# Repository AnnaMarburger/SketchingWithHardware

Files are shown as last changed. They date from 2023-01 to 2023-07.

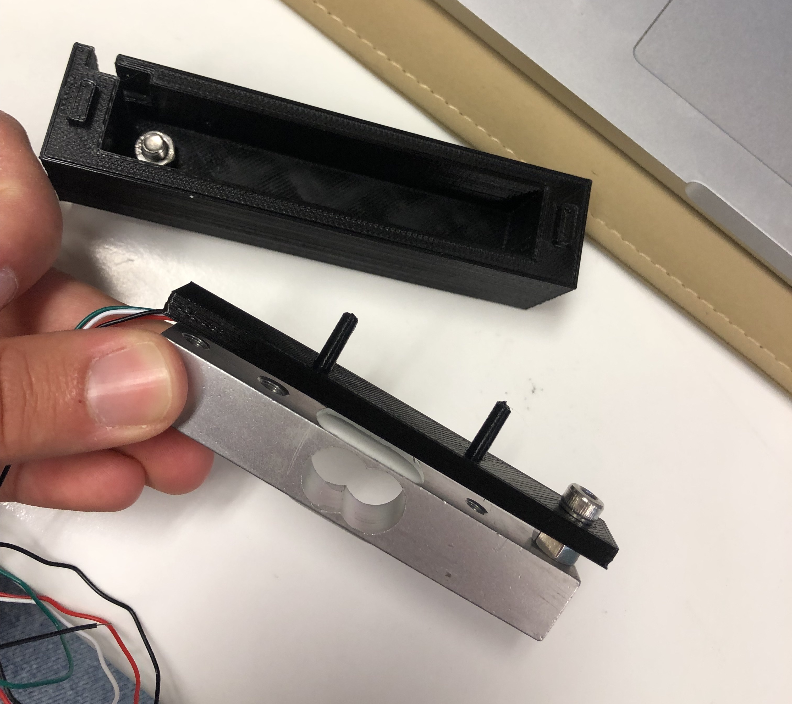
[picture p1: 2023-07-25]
content/posts/media/projekt/assemble_gewichtssensor.jpeg

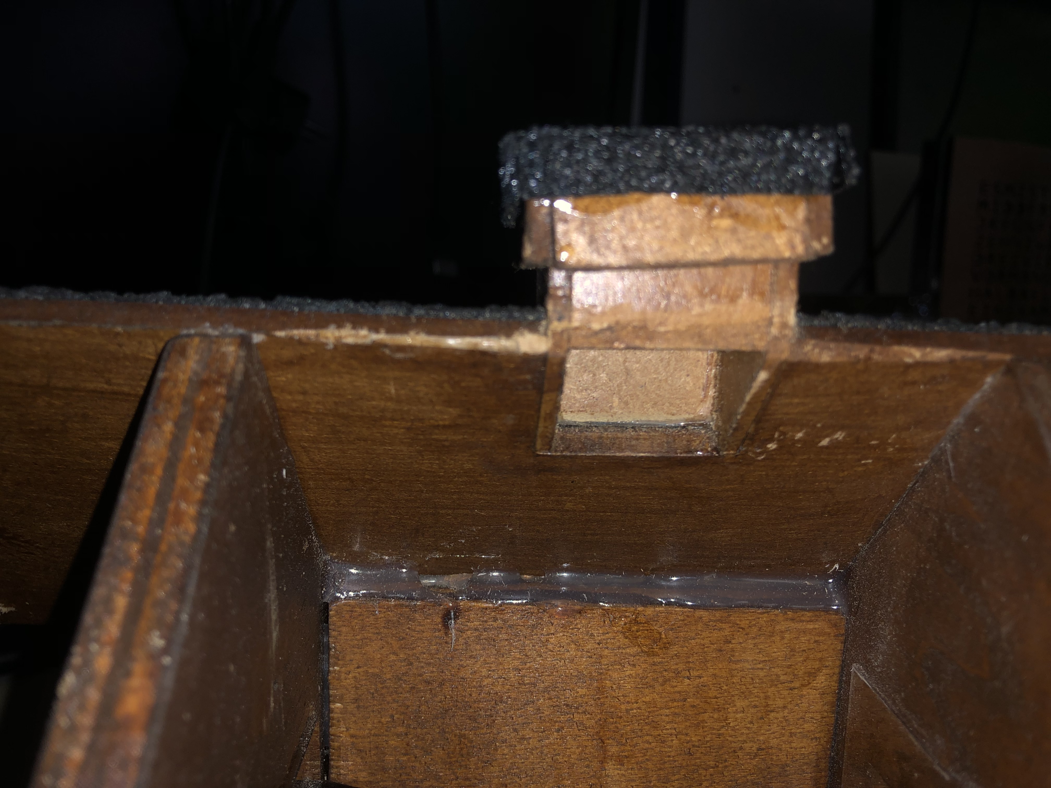
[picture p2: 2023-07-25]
content/posts/media/projekt/dach.jpeg

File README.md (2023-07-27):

### Sketching With Hardware I + II
Im WS 2022/23 und SS 2023 an der Universität. Der Blog findet sich auf: [annamarburger.github.io](https://annamarburger.github.io/swh/).

Im Ordner *birdbooth_files* finden sich alle Dateien, die für den Nachbau des Projekts **BIRD BOOTH** notwendig sind [(Anleitung)](https://annamarburger.github.io/swh/posts/post9/).

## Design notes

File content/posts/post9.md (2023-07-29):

---
title: "09 - Nachbauanleitung: Bird Booth"
date: 2023-07-11T12:28:26+02:00
show_reading_time: true
featured_image: "/media/haus_drawing.png"
draft: false
---

## Einleitung

Das Projekt Bird Booth entstand aus der Idee, auch viel beschäftigten Vogelliebhabern die Möglichkeit zu bieten, ihre Besucher zu sehen, und nicht nur das langsam verschwindende Futter über die Zeit zu beobachten. Das smarte Futterhäuschen liefert Bilder und Gewicht von alle Vögeln, die sich an dem Futter bedienen. Das Gewicht liefert einen zusätzlichen Wiedererkennungswert und lässt Beobachter zum Beispiel auch Rückschlüsse auf Gesundheit und Zustand der tierischen Besucher ziehen.
Bird Booth soll ein langlebiges und umweltfreundliches Vogelhäuschen sein.

{{< rawhtml >}} 
    <br>
{{< /rawhtml >}}
### Materialien und Zubehör

##### Technik
-  ESP32 CAM 2,4 GHz WiFi mit OV2640 Kamera Modul
-  Elektronischer Gewicht Sensor (3kg)
-  HX711 LoadCell Amplifier
-  Vibrationssensor SW420
-  Batterie-Case mit 3x AAA-Batterien(1,5V)

##### Zusätzliches Material
- 2 Lochraster-Platinen
- Kleines Scharnier einschließlich Schrauben
- Holzlasur auf Wasserbasis
- Holz nach Wahl (5 Platten mit 1cm Dicke für Wände und Boden, 4 Platten mit 3mm für das Dach, Zwischenboden und Futterplatte)
- Dachpappe
- 2 kleine Plexiglasplatten
- 2 kleine Magnete
- 2x Schrauben (Maße: Durchmesser  5mm, Kopfdurchmesser max. 9mm, Länge ca 25mm), einschließlich 2 passenden Muttern
- Eine Schraube (Maße: Durchmesser 5mm, Kopfdurchmesser max. 9mm, Länge 15-25mm), einschließlich passender Mutter (Für Sensor-Case unten)
- Eine Schrauben (Maße: Durchmesser 4mm, Kopfhöhe max. 4.5mm, Länge 15-25mm), einschließlich passender Muttern (Für Sensor-Case Innen)
- 8 kleine Nägel
- Holzstab Durchmesser 10mm, Länge 105mm

##### Zubehör
- FTDI232 Adapter (USB auf Serielles TTL) und USB Kabel
- 3D-Drucker mit PLA Filament
- Bandsäge und Stichsäge
- Akku-/Bohrschrauber
- Holzleim, 2-Komponenten-Kleber, Heißkleber
- Kabel, Lötzubehör, Schrumpfschläuche

##### Zum Testen
- Steckplatine
- Jumperkabel

##### Optional
- weiße Acrylfarbe
- kleine, platte Holzstäbchen für die Fensterrahmen
- Makramee-Fäden

{{< rawhtml >}} 
    <br>
{{< /rawhtml >}}
### Dateien-Bibliothek
#### Code
- [Server Code ](https://github.com/AnnaMarburger/smartesfutterhaus)
- [ESP Code ](https://github.com/AnnaMarburger/swh/blob/main/birdbooth_files/esp_code.ino)

#### 3D-Druck-Modelle (.stl)
- [Sensor-Case Deckel ](https://github.com/AnnaMarburger/swh/blob/main/birdbooth_files/sensorcase_deckel.stl)
- [Sensor-Case Zwischenblatt](https://github.com/AnnaMarburger/swh/blob/main/birdbooth_files/sensorcase_zwischenblatt.stl)
- [Sensor-Case Unterteil](https://github.com/AnnaMarburger/swh/blob/main/birdbooth_files/sensorcase_unten.stl)
- [Futterschale Unterteil](https://github.com/AnnaMarburger/swh/blob/main/birdbooth_files/futterschale_unten.stl)
- [Kamera-Case](https://github.com/AnnaMarburger/swh/blob/main/birdbooth_files/cam-case.stl)

#### Lötplan
- [schaltplan.png ](https://github.com/AnnaMarburger/swh/blob/main/birdbooth_files/schaltplan.png)

{{< rawhtml >}} 
    <br>
{{< /rawhtml >}}
## Schritt-für-Schritt Anleitung

### 1. Website programmieren, Server aufsetzen und hosten

{{< figure src="../media/projekt/server_desktop.png" >}}

#### 1.1 Projekt aufsetzen, Umgebungen installieren

Um später die Bilder der Futterhaus-Kamera zusammen mit den Gewichtsdaten von überall einsehen zu können, setzen wir einen Server auf. Dieser soll zum einen POST-Requests mit den Daten, die wir später von dem Kamera Modul senden, annehmen und in einer Datenbank speichern können. Zum anderen soll er Webclients, die unsere Website aufrufen, eine HTML mit den aufgearbeiteten Daten (Bildern) zurückgeben.

Um den Server zu realisieren verwende ich die Laufzeitumgebung [Node Js](https://nodejs.org/de). Ist diese noch nicht installiert, sollte dies zuerst geschehen. 

Nun legen wir ein Verzeichnis an, in welchem wir unsere Anwendung aufbauen. Mit `npm init` wird eine neue package.json Datei erstellt. In dieser können wir unter anderem den Namen unserer Anwendung festlegen, sowie unter “main” den Namen unsere Hauptdatei, die für das Starten des Servers verantwortlich ist. Bevor wir genau diese Datei anlegen, in meinem Fall “app.js”, fügen wir der package.json Datei ein weiteres Attribut hinzu: `“type”:module`. 

Um das Coden einfacher zu  gestalten, verwende ich das Framework  [Express Js](https://expressjs.com)  . Dieses lässt sich mit dem Package Manager npm durch `npm install express` installieren. Dabei ist wichtig, dass wir uns im Verzeichnis unserer Anwendung befinden. Mit `node app.js` kann der Server lokal getestet werden. Hierzu ist zudem das Programm [Postman](https://www.postman.com) hilfreich, das über eine einfache Benutzeroberfläche Server Requests verschicken lässt 

  {{< figure src="../media/projekt/postman_request.png" caption="Screenshot POST-request in Postman">}}

(Achtung: Für Anfragen an lokale Server wird hierbei die Desktop App benötigt).

#### 1.2 Datenspeicherung mit Firebase

Für die Datenspeicherung verwende ich Firebase. Um das Projekt dort anzulegen, wird ein Konto benötigt. Anschließend kann über “Projekt hinzufügen”, ein neues Projekt erstellt werden. Ist dies getan, öffnet sich die Konsole für das Projekt. Dort sollte die App dem Projekt hinzugefügt werden. Da wir eine Webanwendung bauen, wählen wir dort “Web” aus und geben den Namen unseres Servers ein. Über Firebase kann der Server später auch gehostet werden, dann sollte der Haken bei dieser Option gesetzt werden. Ich habe dafür jedoch einen anderen (kostenlosen) Anbieter gewählt: [Render](https://render.com/). Anschließend muss firebase in unserem Projekt installiert werden: `npm install firebase`. Firebase zeigt nun einen Codeblock an:

```jsx
// Import the functions you need from the SDKs you need
import { initializeApp } from "firebase/app";

// Your web app's Firebase configuration
const firebaseConfig = {
  apiKey: "...",
  ...
};

// Initialize Firebase
const app = initializeApp(firebaseConfig);
```

Wichtig hier ist die Firebase Configuration für unsere Anwendung, da diese für jedes angelegte Firebase Projekt individuell ist. Dieser Teil muss also kopiert und in unserer Hauptdatei *app.js* entsprechend ersetzt werden. Nun müssen wir in der Firebase Konsole nur noch unseren Speicher einrichten. Unter “Entwickeln” im Seitenmenü wählen wir “Storage” aus und drücken auf der Seite auf “Jetzt Starten”.  Die Sicherheitsregeln setzen wir (zum Entwickeln) auf öffentlich. In diesem Speicherbucket können wir nun einen Ordner “images” erstellen. Hier lädt unser Server alle einkommenden Bilder hoch. 

  {{< figure src="../media/projekt/screen_firebase.png" caption="Screenshot des Firebase-Storage">}}

Außerdem muss die Datei *data.json* in diesem Storage von Hand erstmals hochgeladen werden, da der Server versucht, diese herunterzuladen, sobald er eine “GET” Request von einem Clienten erhält. Beim allerersten Serverstart würde dieser dementsprechend einen Fehler werfen, wenn er dort keine *data.json* Datei findet.

#### 1.3 Hosting

Für das Hosten des Servers auf Render wird lediglich ein GitHub Repository mit dem Servercode benötigt. Der Anbieter deployed mit jedem Commit den Server erneut. Außerdem gibt es eine Konsole, in der Ausgaben des Servers eingesehen werden können (Hilfreich zum Debuggen). Render selbst führt gut verständlich durch den Hosting Prozess.

#### 1.4 **Aufbau des Servers:**

Der gesamte Code für den Server ist auf folgendem Repo zu finden: 

https://github.com/AnnaMarburger/smartesfutterhaus

1. Die *app.js* Datei, auch die Hauptdatei, die für das eigentliche Erstellen des Servers verantwortlich ist. In dieser Datei werden “POST”, “GET” und “DELETE” Anfragen gehändelt. Einkommende POST Anfragen werden auf Richtigkeit geprüft und anschließend bearbeitet. Bilder werden direkt mit einem eindeutigen Namen (durch Datum+Uhrzeit) im Firebase Storage gesichert. 

2. Die *index.html* Datei ist die Datei, welche an Clienten bei GET Requests geschickt wird. In ihr werden die Buttons zum Filtern und Sortieren definiert. Außerdem sind in ihr die Dateien *gallery.js* und *style.css* verlinkt.

Im *Public Ordner*, welchen wir als solchen in *app.js* deklarieren (dies ist wichtig, um Clienten den Zugriff auf benötigte Dateien wie z.B. stylesheets möglich zu machen, die wir nicht per se mitschicken):

3. *gallery.js* ist die JavaScript Datei, die sich um das dynamische Anzeigen der Daten auf der Website kümmert. Sie liest aus der “data.json” jeweils Bildname, zugehöriges Gewicht und Datum aus und zeigt diese Daten für jeden Eintrag als Galerie-Item auf der Website an. Des Weiteren händelt sie die Filter- und Sortierungs-Optionen, die durch die Buttons auf der Seite getriggert werden. 

4. In der Datei *style.css* wird das Aussehen der Website entsprechend festgelegt.

5. Die bereits erwähnte *data.json* Datei verwaltet die Metadaten zu jedem Bild, das den Server erreicht. Dazu gehören Name der Bilddatei, sodass sie in den Files gefunden werden kann, das gemessene Gewicht des zugehörigen Vogels sowie einen Datumsstempel, der beim Empfangen des Bildes hinzugefügt wurde.

Der *Uploads Ordner* enthält die Bilddateien zum Anzeigen nach Herunterladen aus dem Firebase Speicher.

{{< rawhtml >}} 
    <br>
{{< /rawhtml >}}
### 2. Kameramodul

#### 2.1 Schaltplan

Unsere Kamera-Komponente besteht aus zwei Teilen: Zum einen die ESP32-Cam, die mit einem ESP32 Microchip arbeitet, zum anderen das OV2640 Kameramodul, sprich die Kamera selbst. Werden beide Teile getrennt geliefert, so muss der längliche Klipser auf der ESP32-Cam vorsichtig aufgemacht und das Kameramodul so reingeschoben werden, dass die Kamera nach vorne zeigt und sicher hält.

Da die ESP32-Cam keinen USB-Anschluss mitbringt, benötigen wir, um sie zu programmieren, einen USB-to-TTL Adapter, wie zum Beispiel den FTDI. Diesen können wir mithilfe eines Breadbords anschließen:

  {{< figure src="../media/projekt/steckplatine.jpeg" width="60%"  caption="ESP+FTDI auf Steckplatine">}}

Dabei sollten wir darauf achten, dass auf dem Adapter die Bridge zu 5V gesetzt ist. Zwar läuft der Esp laut Dokumentation auch mit 3.3V, jedoch wurden hierbei zahlreiche Probleme in Online Foren reported. Zusätzlich müssen wir die ESP32-Cam, um Code hochladen zu können, in den “Flashing Mode” setzen. Dies machen wir, indem wir die Pins GPIO0 und GND verbinden. Der Schaltplan sieht demnach folgendermaßen aus:

  {{< figure src="../media/projekt/schaltplan_esp.jpeg" caption="Schaltplan ESP+FTDI">}}

#### 2.2 Programmieren

 Um den ESP-32 Microchip programmieren zu können, müssen wir das Board in der Arduino IDE installieren. Dazu fügen wir in den Einstellungen folgenden Link dem Feld “Additional boards manager URLs” hinzu und speichern:

https://dl.espressif.com/dl/package_esp32_index.json 

Im Boards Manager können wir nun nach “esp32” suchen und installieren. Anschließend sollten wir unter Tools>Board>esp32 die “AI Thinker Esp32 Cam” auswählen können. Unter Port wählen wir den entsprechenden USB Port aus, an welchem wir den Adapter eingesteckt haben.

  {{< figure src="../media/projekt/select_AIThinkerCam.png" caption="Screenshot Board-Auswahl">}}

Unter File > Examples gibt es verschiedene Beispielprogramme, um den ESP zu testen, so auch zum Beispiel auch ein Programm, dass auf einem lokalen Server einen Livestream der Kamera startet und die verschiedensten Einstellungen treffen lässt. Der Code findet sich unter File > Examples > ESP32 > Camera > CameraWebServer. 

Während dem Upload des Codes, wenn auf der Konsole “Connecting…” erscheint, muss das Board einmal resettet werden. Auf der Rückseite gibt es dazu einen kleinen Reset-Knopf. Da man daran aber schlecht herankommt, wenn man ein Breadboard verwendet, kann man alternativ das Kabel zu 5V am Board kurz aus- und wieder einstecken.

Nun sollten wir dazu bereit sein, unseren eigentlichen Code für die ESP32-Cam zu schreiben. Wir erstellen eine neue Arduino Datei. Zunächst brauchen wir folgende Libraries:

```cpp
#include <Arduino.h>
#include <WiFi.h>
#include <WiFiClientSecure.h>
#include "soc/soc.h"
#include "soc/rtc_cntl_reg.h"
#include "esp_camera.h"
```

Anschließend legen wir folgende Variablen für die WiFi Connection fest:
```cpp
//WIFI
const char* ssid = "INSERT_YOUR_SSID";
const char* password = "INSERT_PASSWORD_FOR_SSID";
String serverName = "INSERT_SERVER_URL"; //for me: smartesfutterhaus.onrender.com
String serverPath = "/"; 
const int serverPort = 443; //server port for HTTPS
WiFiClientSecure client;
```

Hierbei müssen SSID und Passwort natürlich mit den eigenen Werten gefüllt werden, sprich mit Name und Passwort der WLAN-Verbindung. Auch die Server-URL muss individuell eingetragen werden. 

Um die AI-Thinker Camera vom ESP32 zu verwenden, müssen wir folgende Pins definieren:
```cpp
// CAMERA_MODEL_AI_THINKER
#define PWDN_GPIO_NUM     32
#define RESET_GPIO_NUM    -1
#define XCLK_GPIO_NUM      0
#define SIOD_GPIO_NUM     26
#define SIOC_GPIO_NUM     27
#define Y9_GPIO_NUM       35
#define Y8_GPIO_NUM       34
#define Y7_GPIO_NUM       39
#define Y6_GPIO_NUM       36
#define Y5_GPIO_NUM       21
#define Y4_GPIO_NUM       19
#define Y3_GPIO_NUM       18
#define Y2_GPIO_NUM        5
#define VSYNC_GPIO_NUM    25
#define HREF_GPIO_NUM     23
#define PCLK_GPIO_NUM     22
```

Nun konfigurieren wir in der setup Methode zum einen die WiFi-Verbindung (wir verwenden den STA Modus), zum anderen die Kamera (diese ist durch das Modell erneut vorgegeben).
Zuletzt versuchen wir, die Cam zu initialisieren. Tritt hierbei ein Fehler auf, soll eine Fehlermeldung ausgegeben werden und nach einem kurzen Delay ein Neustart des ESP hervorgerufen werden. 
```cpp
//SETUP
void setup() {
  WRITE_PERI_REG(RTC_CNTL_BROWN_OUT_REG, 0); //BROWN OUT DETECTOR
  Serial.begin(115200); //BAUD RATE

  //WIFI setup
  WiFi.enableSTA(true);
  WiFi.mode(WIFI_STA);

  //CAM config
  camera_config_t config;
  config.ledc_channel = LEDC_CHANNEL_0;
  config.ledc_timer = LEDC_TIMER_0;
  config.pin_d0 = Y2_GPIO_NUM;
  config.pin_d1 = Y3_GPIO_NUM;
  config.pin_d2 = Y4_GPIO_NUM;
  config.pin_d3 = Y5_GPIO_NUM;
  config.pin_d4 = Y6_GPIO_NUM;
  config.pin_d5 = Y7_GPIO_NUM;
  config.pin_d6 = Y8_GPIO_NUM;
  config.pin_d7 = Y9_GPIO_NUM;
  config.pin_xclk = XCLK_GPIO_NUM;
  config.pin_pclk = PCLK_GPIO_NUM;
  config.pin_vsync = VSYNC_GPIO_NUM;
  config.pin_href = HREF_GPIO_NUM;
  config.pin_sscb_sda = SIOD_GPIO_NUM;
  config.pin_sscb_scl = SIOC_GPIO_NUM;
  config.pin_pwdn = PWDN_GPIO_NUM;
  config.pin_reset = RESET_GPIO_NUM;
  config.xclk_freq_hz = 20000000;
  config.pixel_format = PIXFORMAT_JPEG;

  // init with high specs to pre-allocate larger buffers
  if(psramFound()){
    config.frame_size = FRAMESIZE_SVGA;
    config.jpeg_quality = 10;  //0-63 lower number means higher quality
    config.fb_count = 2;
  } else {
    config.frame_size = FRAMESIZE_CIF;
    config.jpeg_quality = 12;  //0-63 lower number means higher quality
    config.fb_count = 1;
  }
  
  // CAM init
  esp_err_t err = esp_camera_init(&config);
  if (err != ESP_OK) {
    Serial.printf("Camera init failed with error 0x%x", err);
    delay(1000);
    ESP.restart();
  }
}
```

In einer zusätzlichen Methode schreiben wir folgenden Code, um uns mit dem WiFi zu verbinden:
```cpp
void connectWiFi(){
  WiFi.enableSTA(true);
  WiFi.mode(WIFI_STA);
  delay(10);
  WiFi.begin(ssid, password);
  int counter = 0;

  while( WiFi.status() != WL_CONNECTED) {
    delay(1000);
    Serial.println("Connecting to WiFi.. > status : " + String(WiFi.status()));
    counter++;
    if(counter >= 25){
      WiFi.begin(ssid, password);
      counter = 0;
    }
  }
}
```
Diesen werden wir später jedes Mal aufrufen, wenn wir den ESP aus seinem sleep modus aufwecken. 

Außerdem schreiben wir eine Methode, die für das tatsächliche Versenden des Fotos verantwortlich ist. Dabei holen wir uns zuerst einen Pointer zum Kamera Frame-Buffer (und starten den ESP neu, falls dies fehlschlagen sollte). Anschließend bauen wir eine Verbindung zu unserem Server auf. Schließlich schreiben wir die Request, senden sie ab und warten auf die Antwort des Servers (dies ist hauptsächlich für Debugging-Zwecke nötig und kann letztendlich weggelassen werden, da wir die Antwort nicht weiter verarbeiten. Alternativ kann bei einer Fehlerausgabe ein erneutes Versenden ausgelöst werden; Darauf habe ich, um die Code Komplexität zu verringern, verzichtet).

```cpp
void sendPhoto() {
  String getAll;
  String getBody;
	
  //get Camera Capture
  camera_fb_t * fb = NULL;
  fb = esp_camera_fb_get();
  if(!fb) {
    Serial.println("Camera capture failed");
    delay(1000);
    ESP.restart();
  }
  
  Serial.println("Connecting to server: " + serverName);
  
  client.setInsecure(); //skip certificate validation
  if (client.connect(serverName.c_str(), serverPort)) {

    Serial.println("Connection successful!");  

    //send request           
    String head1 = "--XXX\r\nContent-Disposition: form-data; name=\"password\"\r\n\r\nSWH2023\r\n--XXX\r\nContent-Disposition: form-data; name=\"weight\"\r\n\r\n";
    String head2 = head1 + weight;
    String head = head2 + "\r\n--XXX\r\nContent-Disposition: form-data; name=\"img\"; filename=\"esp32-cam.jpg\"\r\nContent-Type: image/jpeg\r\n\r\n";
    String tail = "\r\n--XXX--\r\n";
    
    uint32_t imageLen = fb->len;
    uint32_t extraLen = head.length() + tail.length();
    uint32_t totalLen = imageLen + extraLen;
  
    client.println("POST " + serverPath + " HTTP/1.1");
    client.println("Host: " + serverName);
    client.println("Content-Length: " + String(totalLen));
    client.println("Content-Type: multipart/form-data; boundary=XXX\r\n\r\n");
    client.print(head);
  
    //send img
    uint8_t *fbBuf = fb->buf;
    size_t fbLen = fb->len;
    for (size_t n=0; n<fbLen; n=n+1024) {
      if (n+1024 < fbLen) {
        client.write(fbBuf, 1024);
        fbBuf += 1024;
      }
      else if (fbLen%1024>0) {
        size_t remainder = fbLen%1024;
        client.write(fbBuf, remainder);
      }
    }   
    client.print(tail);
    
    esp_camera_fb_return(fb);
    
    int timoutTimer = 180000;
    long startTimer = millis();
    boolean state = false;
    
    //read answer
    while ((startTimer + timoutTimer) > millis()) {
      Serial.print(".");
      delay(500);      
      while (client.available()) {
        char c = client.read();
        if (c == '\n') {
          if (getAll.length()==0) { state=true; }
          getAll = "";
        }
        else if (c != '\r') { getAll += String(c); }
        if (state==true) { getBody += String(c); }
        startTimer = millis();
      }
      if (getBody.length()>0) { break; }
    }
    Serial.println();
    client.stop();
    Serial.println(getBody);
  }
  else {
    Serial.println("Connection to " + serverName +  " failed.");
  }
}
```

Achtung: Um den Code zu testen, muss "weight" durch eine beliebige Zahl ersetzt werden. Diese Variable haben wir bisher noch nicht definiert. Dies werden wir in Abschnitt 4 tun, wenn es um den Gewichtssensor geht.
Um beim Testen das Output des Programms sehen zu können, öffnen wir unter Tools > Serial Monitor den Serial Monitor und beachten dabei, dass er auf die richtige BAUD Rate (hier 115200) eingestellt ist.

**Troubleshooting**: Beim Hochladen von Code auf den ESP kommt es gerne mal zu Problemen, oftmals liegt es an manelhafter Stromversorgung. Hier hilft Google weiter. Eine für mich hilfreiche Seite war: [espressif docs](https://docs.espressif.com/projects/arduino-esp32/en/latest/troubleshooting.html).

{{< rawhtml >}} 
    <br>
{{< /rawhtml >}}
### 3. Weckfunktion mit Vibrationssensor

Damit der ESP in den light sleep geschickt werden kann, während keine Vögel zu Besuch sind, wird ein Vibrationssensor benötigt, um den ESP auch wieder aufwecken zu können. Dazu ergänzen wir unseren Code folgendermaßen:

- Wir ergänzen in der setup Methode am Ende: 
    ```cpp
    //lightsleep init
    pinMode(15, INPUT);
    gpio_wakeup_enable(GPIO_NUM_15, GPIO_INTR_HIGH_LEVEL);
    esp_sleep_enable_gpio_wakeup();
    WiFi.disconnect(true);
    Serial.println("Gleich schlafen"); //debug output
    Serial.flush(); 
    delay(100);
    esp_light_sleep_start();
    delay(10);
    ```
    Hierbei ist Pin 15 der Pin, an den wir den Vibrationssensor anschließen. Wir legen diesen als WakeUp-Pin fest und trennen anschließend die WiFi-Verbindung. Dies ist nötig, um sie nach Erwachen aus dem sleep modus fehlerfrei wiederherstellen zu können. Anschließend starten wir direkt in den light sleep. Wenn der ESP durch ein Signal des Vibrationssensor geweckt wird, läuft der Code einfach weiter.

- Wir schreiben eine Methode, die mit jedem Erwachen aus dem sleep modus ausgeführt wird, unsere sogenannte WakeUp-Routine:
    ```cpp
    void wakeUpRoutine(){
        //reconnect to wifi and send image to server
        connectWiFi();
        sendPhoto();

        //back to sleep
        WiFi.disconnect(true);
        Serial.flush();
        delay(100);
        esp_light_sleep_start();
        delay(10);
        }
    ```
    Nach Senden des Fotos müssen wir, wie oben bereits erklärt, die WiFi Verbindung wieder trennen, bevor wir den ESP wieder in den sleep modus schicken.

- Nun können wir die loop-Methode schreiben, die sich so lange wiederholt, wie der ESP mit Strom versorgt wird:
    ```cpp
    void loop() {
        Serial.println("......... Woke Up ..................."); //debugging print
        wakeUpRoutine();
        delay(100);
    }
    ```
    In dieser brauchen wir nun lediglich unsere WakeUp-Routine aufzurufen. Ein loop-Durchgang entspricht also einem “Aufwachen”, da der ESP am Ende der WakeUp-Routine in den sleep modus versetzt wird.

{{< rawhtml >}} 
    <br>
{{< /rawhtml >}}
### 4. All about “Gewichtssensor”
Um mit den Daten des Gewichtssensors etwas anfangen zu können, brauchen wir ein Amplifier Modul (HX711). Der Schaltplan für diese beiden Komponenten sieht folgendermaßen aus:

{{< figure src="../media/projekt/schaltplan_loadcell.png" caption="Schaltplan Gewichtssensor">}}

Hierbei entsprechen die Farben der Kabel des Sensors auf dem Bild den Farben in echt und sollten dementsprechend verlötet werden. Um sicherzugehen ist es aber ratsam, in die Dokumentation der eigenen Teile zu schauen, falls Abweichungen auftreten. 

Das Schaubild zeigt außerdem, wie wir den Gewichtssensor montieren. Dazu brauchen wir folgende Bauteile:

{{< figure src="../media/projekt/bauteile_gewichtssensor.jpeg" width="60%"  caption="Gewichtssensor Bauteile">}}

- 3D-Modelle: Sensor-Case Deckel, Unterteil und Zwischenblatt
- Gewichtssensor mit Amplifier Modul
- 2 Schrauben einschließlich passender Muttern
- Holzstange

Die beiden Muttern dienen dabei als Spacer zwischen dem Gewichtssensor und dem unteren Teil des Cases, bzw. dem Waagblatt, das die Sitzstange hält und zwischen oberen Teil des Cases und Gewichtssensor liegt. Dies ist wichtig, damit der Sensor genug Platz hat, um bei Belastung nach unten gebeugt zu werden.

{{< figure src="../media/projekt/assemble_gewichtssensor.jpeg" width="60%"  caption="Gewichtssensor zusammenbauen">}}

Ist das Gehäuse zusammengesetzt, werden in die Holzstange (nachdem sie ebenfalls lasiert wurde) zwei Löcher mit 3mm Durchmesser gebort, so dass sie auf die beiden herausschauenden Stäbe gesteckt werden kann. Damit sie sicher hebt, habe ich sie mit 2-Komponenten-Kleber festgeklebt, dies sollte jedoch erst geschehen, wenn der Gewichtssensor zuverlässig funktioniert und das Case nicht mehr geöffnet werden muss. Das Case an sich habe ich nicht verklebt, da es durch den Steck-Mechanismus bereits ausreichend stabile Haftung vorwies.

{{< figure src="../media/projekt/gewichtssensor.jpeg" width="60%"  caption="Gewichtssensor fertig">}}

Um mit jedem Bild auch das aktuell gemessene Gewicht an den Server zu übermitteln, ergänzen wir den bisherigen Code für unseren ESP folgendermaßen:
- Das HX711 Modul benötigt eine Library, die wir inkludieren müssen:
    ```cpp
    #include "HX711.h"
    ```
    
- Des Weiteren definieren wir folgende Variablen, noch vor der setup-Methode:
    ```cpp
    //LOADCELL
    const int LOADCELL_DOUT_PIN = 13;
    const int LOADCELL_SCK_PIN = 12;
    const int calibrationfaktor = 380; //insert your own!
    long weight;
    HX711 scale;
    ```
    Die zwei Pins für DOUT und SCK entsprechen den Pins, die wir am ESP für den Sensor auswählen, ich habe hier Pin 12 und 13 gewählt.
    WICHTIG: Der Calibration-Factor ist für jeden Sensor ein anderer. Um diesen herauszufinden, müssen einige Objekte mit bekanntem Gewicht mit dem Sensor gewogen werden. Der Faktor berechnet sich dann folgendermaßen: 
    
    Calibration-Factor = Gemessenes Gewicht / Bekanntes Gewicht. 
    
    Es empfiehlt sich, dies mit einer gewissen Anzahl an Objekten zu machen und anschließen den Mittelwert der erhaltenen Faktoren zu nehmen, um am Ende möglichst genaue Daten zu erhalten.

- In der setup-Methode müssen wir nun unsere Waage initialisieren
    ```cpp
    //LOADCELL init
    scale.begin(LOADCELL_DOUT_PIN, LOADCELL_SCK_PIN);
    scale.set_scale(calibrationfaktor);
    scale.tare(5);
    ```
    Mit `scale.tare()` setzen wir die Waage auf Null. Wenn diese Methode aufgerufen wird, sollte sich also kein Gewicht auf dem Sensor befinden.

- Nun passen wir noch die WakeUp-Routine des ESP’s an, indem wir vor dem Senden des Fotos zunächst das Gewicht messen, und anschließend das Senden an den Server nur durchführen, wenn das Gewicht einen bestimmten Schwelle überschreitet. Dies verhindert, dass Fotos gesendet werden, wenn der Vibrationssensor fehlerhaft ausgelöst wurde (zum Beispiel durch ein fallendes Blatt oÄ.). Ich habe als Schwellwert 3 Gramm gewählt.
    ```cpp
    void wakeUpRoutine(){
        //get weight
        if (scale.is_ready()) { 
            weight = scale.get_units(20); //get the average of 20 readings
            Serial.print("Gewicht: "); //debug output
            Serial.println(weight);
        } else {
            Serial.println("HX711 not found.");
            weight = 0;
        }

        //check if an object is actually there or if scale empty
        if(weight > 3){
            //reconnect to wifi and send image to server
            connectWiFi();
            sendPhoto();
        }

        //back to sleep
        WiFi.disconnect(true);
        Serial.flush();
        delay(100);
        esp_light_sleep_start();
        delay(10);
    }
    ```

{{< rawhtml >}} 
    <br>
{{< /rawhtml >}}
### 5. Finaler Schaltplan, Stromversorgung

Um die bisher einzelnen Komponenten zusammenzuführen, soll folgender Schaltplan verwendet werden.

{{< figure src="../media/projekt/schaltplan.png" caption="Vollständiger Schaltplan aller Komponenten">}}

Als Stromversorgung verwenden wir ein Batterie-Case, dass Platz für 3 AAA Batterien beinhaltet. Da die AAA Batterien jeweils 1.5V liefern, erhalten wir so insgesamt 4.5V. Da alle Komponenten mit 3.3-5V arbeiten, brauchen wir so keine zusätzlichen Widerstände und versorgen gleichzeitig alle Komponenten mit genügend Strom.

Tabelle der Verknüpfungen: 

| HX711 \|  | ESP32-Cam \| | SW420  |
| --- | --- | --- |
| DT | GPIO13 | - |
| SCK | GPIO12 | - |
| - | GPIO15 | DO |

Ich habe jeweils Vibrationssensor und Amplifier Modul auf eine Platine sowie den ESP auf eine eigene Platine verlötet. Dies ist der Verteilung der Komponenten im Häuschen verschuldet. Während Vibrationssensor und Amplifier unter die Futterschale gehören, muss die ESP-Cam gegenüber der Sitzstange im Häuschen-Inneren angebracht werden. Es empfiehlt sich, die Cam erst später während dem Häuschenfertigungsprozess final zu verlöten, da erst dann abgeschätzt werden kann, wie lang die Drähte ins Häuschen-Innere sein müssen.

{{< rawhtml >}} 
    <br>
{{< /rawhtml >}}
### 6. Häuschenfertigung

Das Gehäuse für den Gewichtssensor wurde bereits angesprochen. So bleibt noch die Futterschale und das Häuschen selber.

Für die Futterschale habe ich den unteren Teil, in den dann Vibrationssensor und Amplifier Modul gelegt werden, 3D gedruckt. Da das Gehäuse des Gewichtssensors keinen Platz für Schrauben bietet und es nicht nötig ist, dass der untere Teil der Futterschale abnehmbar ist, wird er mit 2-Komponenten-Kleber an den unteren Teil des Gewichtssensor-Gehäuses geklebt, so dass beide Teile nach unten bündig abschließen.

{{< figure src="../media/projekt/futterschale_untererTeil.jpeg" width="60%"  caption="Futterschale und Sensor-Case">}}

Die  beiden kleinen Schraubenlöcher auf der Oberseite waren ursprünglich dazu da, um eine Platte von oben drauf zu schrauben, um so die Technik zu schützen. Wird diese Variante präferiert, können diese beibehalten werden, ansonsten sind sie überflüssig und können auch aus dem 3D Modell entfernt werden.

Um das Häuschen selbst zu bauen, sollen aus beliebigen Holz je nach gewünschter Größe des Hauses passende Wände sowie ein Boden ausgesägt werden. Zwei Wände müssen hierbei mit spitzer Oberseite zugesägt werden. Eine von diesen soll die Vorderseite werden, die andere die Rückseite. In die Vorderseite müssen folgende Ausschnitte:

- Zwei Löcher auf Höhe der Schrauben der Futterschale (siehe oben), Durchmesser 5mm
- Ein rechteckiges Fenster auf Höhe der oberen Seite der Futterschale (Dabei muss bedacht werden, dass ein Deckel später dazugehört, die Schale wird nicht offen bleiben). Durch dieses soll später das Futter in die Futterschale gelangen.
- Ein weiteres Loch, etwas unterhalb der Futteröffnung, um die Kabel ins Häuschen-Innere zu führen.
- Ein weiteres Fenster oberhalb des vorherigen, durch welches später die ESP-Cam fotografiert.

Dazu habe ich eine Stichsäge verwendet, während ich zum Aussägen der Platten selber eine Bandsäge benutzt habe.

{{< figure src="../media/projekt/haus_vorne.jpeg" width="60%" caption="Vorderseite des Häuschens">}}

Vor dem Verkleben sollte das Holz wetterfest gemacht werden. Hierbei habe ich einen wasserbasierte Acryllasur (in der Farbe Nussbaum) verwendet. Die Lasur sollte für die Sicherheit der Vögel eine giftigen Inhaltsstoffe enthalten. Die Ränder der Fenster können optional mit mit kleinen, zurechtgeschnittenen Holzstäbchen versehen werden, um die Kanten zu verstecken. Dadurch entstehen die oben zu sehenden Fensterrahmen. An das obere Fenster wird von innen eine kleine Plexiglasplatte geklebt, um die Cam zu schützen. Hierzu habe ich ebenfalls 2-Komponenten-Kleber verwendet. Bei der Holzplatte für die Rückseite des Häuschens hab ich das Prozedere für das obere Fenster wiederholt, jedoch in ein bisschen größer in vertikaler Hinsicht. Somit ist später von Außen zu sehen, wie viel Futter noch im Häuschen vorhanden ist.

{{< figure src="../media/projekt/haus_rueckseite.jpeg" width="60%" caption="Fenster in der Rückseite des Häuschens">}}

Um später das Batterie-Case aus dem “Keller” herausnehmen zu können, wird eine kleine Seitentür auf eine Seite des Hauses gebaut. Dazu Sägen wir ein Rechteck in eine der Seitenwände und verschrauben ein kleines Scharnier mit dem ausgeschnittenen Holzstück und der Seitenwand.

{{< figure src="../media/projekt/keller.jpeg" width="60%" caption="Seitentür für den Keller">}}

Beide Seitenwände, Boden und Rückseite können nun in diesem Stadium bereits mit Holzleim zusammengeklebt werden. Dabei sollte auf genug Ruhezeit geachtet werden, um den Leim trocknen zu lassen. Es empfehlen sich außerdem Klammern, die die Komponenten während dem Trocknen zusammenhalten. Für den Zwischenboden im Häuschen, der den “Keller”, in dem später das Batteriecase verstaut wird, vom oberen Teil des Häuschens trennt, werden vier Holzstückchen an die Innenwände auf Höhe der Futteröffnung. Es macht durchaus Sinn, den Zwischenboden ein wenig schräg (hinten höher als vorne) anzubringen, damit das Futter später leichter herausrutscht. Dabei muss, wie auf dem Bild zu sehen, eine Kuhle für die Kabel auf einer Seite gefeilt werden.

{{< figure src="../media/projekt/haus_innen_zwischenboden.jpeg" width="60%" caption="Haus von Innen, Zwischenboden">}}

Als nächstes drucken wir das Gehäuse für die ESP-Cam. Das Gehäuse hat an den Innenwänden zwei Schienen. So kann mit Hilfe eines kleinen Holzstäbchens, an dem dann der ESP befestigt wird, die Cam beliebig nach vorne und hinten verstellt werden. Dies ermöglicht ein passgenaues Einstellen der Cam, um möglichst gute Bilder im Endeffekt zu erhalten. Das Case wird mit 2-Komponenten-Kleber auf der Innenseite des Fensters festgeklebt. Die genaue Höhe sollte vorher durch Testbilder ermittelt werden.

{{< figure src="../media/projekt/haus_innen_cam_offen.jpeg" width="60%" caption="Kamera Case und ESP">}}

Die Futterschale wird mit zwei Schrauben und zwei Muttern an der Häuschenvorderseite festgeschraubt und die Kabel von Gewichts- und Vibrationssensor durch die entsprechende Öffnung geführt. Es empfiehlt sich, diese vorher mit einem Schrumpfschlauch zu umhüllen, um zusätzlichen Schutz zu bieten. Auf die Unterseite des Cam-Case  hab ich eine kleine Holzplatte geklebt, die ein kleines bisschen weiter ins Innere des Häuschens ragt.Damit schließt die spätere,abnehmbaare Rückwand des Cases bündig mit dem Boden ab. Für meine Cam stellte sich heraus, dass 30 mm Abstand zur Vorderwand eine gute Einstellung für das Sichtfeld der Kamera ist. Ist die Kamera befestigt, so wird noch ein Magnet an einem Holzstäbchen davor geklebt. Um die Technik am ESP zu schützen, habe ich den Magnet zusätzlich mit Isolierband umwickelt.

{{< figure src="../media/projekt/haus_innen_cam.jpeg" width="60%" caption="Kamera Case fertig">}}

So können wir auf einer weiteren kleinen Holzplatte in Größe der Öffnung des Kamera-Cases einen weiteren Magnet befestigen und somit einen abnehmbaren Deckel für das Case bauen, so dass der ESP zugänglich bleibt.

{{< figure src="../media/projekt/haus_innen_kabel.jpeg" width="60%" caption="Kabelführung ESP">}}

Schließlich werden zwei weitere lasierte Holzplatten benötigt, um das Dach des Häuschens zu bauen. Dabei ist darauf zu achten, dass diese lang genug sind, um die Futterschale und Sitzstange vor dem Häuschen zu schützen. Mit ein wenig Dachpappe werden diese nochmal extra vor Witterung geschützt. Mit jeweils vier Nägeln, einen für jede Ecke, wird die Pappe auf die Holzplatte genagelt. Eine Seite des Daches habe ich mit Holzleim festgeklebt und von Innen kleine, durch Unregelmäßigkeiten entstandene Lücken, mit Heißkleber abgedichtet. Auf diese Seite des Daches habe ich auch einen kleinen Schornstein eingebaut, einschließlich eines Deckels. Durch den Schornstein kann Futter nachgefüllt werden, ohne das Dach des Häuschens abnehmen zu müssen.

{{< figure src="../media/projekt/dach.jpeg" width="60%" caption="Dach von Innen">}}

Auf der anderen Dachseite werden in einem Rechteck so vier Holzstücke geklebt, dass sich das Dach passgenau auf das Häuschen setzen lässt. Dabei muss in das Holzstück, dass an der oberen Seite des Daches sitzt, eine Auskerbung gesägt werden, um den Schornstein freizuhalten (siehe Bild).

{{< figure src="../media/projekt/dachplatte.jpeg" width="60%" caption="Abnehmbare Dachplatte">}}

Zuletzt soll die Futterschale vervollständigt werden. Zwischen Hausvorderwand und oberen Teil des Gewichtssensor-Case kleben wir auf beiden Seiten zwei Holzstücke auf solcher Höhe, dass zwischen ihnen und dem unteren, 3D gedruckten Teil der Futterschale eine kleine Holzplatte passt. Diese sägen wir uns zurecht und können sie nun als herausschiebbaren Boden für die Futterschale verwenden.

{{< figure src="../media/projekt/Futterschale_boden.jpeg" width="60%" caption="Futterschale">}}

Da bei mir das Loch für die Kabelführung etwas zu hoch war, habe ich ein weiteres Holzstück an die Hauswand geklebt, um die Kabel zu verstecken.

Zuletzt habe ich ein paar Makramee-Fäden verwendet, um kleine Gardinen an das vordere Fenster zu kleben.

{{< figure src="../media/projekt/fertigeshaus.jpg" width="60%" caption="fertiges Häuschen">}}

{{< rawhtml >}} 
    <br>
{{< /rawhtml >}}
## Lizensierung
{{< rawhtml >}} 
<br />This work is licensed under a <a rel="license" href="http://creativecommons.org/licenses/by-nc-sa/4.0/">Creative Commons Attribution-NonCommercial-ShareAlike 4.0 International License</a>.
{{< /rawhtml >}}

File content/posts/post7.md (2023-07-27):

---
title: "07 - Abschlusspost"
date: 2023-03-01T22:08:49+01:00
show_reading_time: true
featured_image: "/media/qboy3.jpeg"
draft: false
---

###  Rückblick
Das erste Semester von Sketching with Hardware begann damit, dass wir eine Präsentation über ein selbst gewähltes Projekt, welches wir gerne verwirklichen würden, wenn wir alle dazu nötigen Fähigkeiten bereits hätten, hielten. Ich entschied mich damals für eine automatische Bewässerungsanlage und stellte fest, dass ich eine sehr gute Anleitung und ggf. Unterstützung brauchen würde, um dieses Projekt umzusetzen, da ich bisher weder mit Lötkolben, 3D-Drucker oder gar einem Arduino gearbeitet hatte.
Während dem Semester lernten wir all diese Dinge an den jeweiligen Labortagen kennen und arbeiteten Stück für Stück an unserem Übungsprojekt weiter. Das E-Technik Labor half, den Schaltplan für den Gameboy aufzustellen, das Microcontroller-Labor, das Spiel auf dem Arduino zum Laufen zu bringen. 

Besonders wichtig für das Projekt wurde der Tag im Lab, als wir das Löten lernten. Während wir jedoch dort nur einen Widerstand an eine freie Steckplatine löteten, wurde ich beim Projekt vor ganz andere Herausforderungen gestellt: Wenig Platz, brüchige Kabel und falsche Verlötungen (und die damit einhergehende notwendige Entfernung des Lötzinns). Im Nachhinein hätte ich mich also über ein wenig mehr Übung im Löten gefreut. Besonders gut gefiel mir die Verbindung von Theorie und Praxis in diesem Modul. Die Vorlesungen wurden aufschlussreich und kompakt gehalten und anschließend durch einen praktischen Teil vertieft.

Rückblickend auf die Präsentation zu Beginn des Semesters stelle ich fest, dass ich mein ausgesuchtes Projekt nun ohne größere Probleme selbst bewältigen könnte. Notwendige Teile wüsste ich 3D zu drucken und auch beim Verkabeln und Löten der Bestandteile sehe ich keine Hindernisse mehr.

#### Prozess Kuhboy (in Bildern):

{{< figure src="../media/qboy1.jpeg" >}}
{{< figure src="../media/qboy2.jpeg" >}}
{{< figure src="../media/qboy3.jpeg" >}}

### Semesterprojekt - Abschlusspräsentation

Das Semester endete mit einer Abschlusspräsentation aller Projekte. Interessant waren die doch teilweise sehr unterschiedlichen Verwirklichungen bei gleichen Rahmenbedingungen anzusehen. Um unsere Projekte vorzustellen, entwarf jeder zusätzlich ein Plakat. Diese wurden ausgedruckt und jeweils zu den Projekten aufgehangen.

{{< figure src="../media/Poster_QBoy.png" >}}

Es machte Spaß, zum einen bei den anderen Projekten vorbeizuschauen und zu sehen, was alles umgesetzt wurde, aber auch zum anderen, das eigene Projekt vorzustellen und die Ideen und den Prozess dahinter zu erklären, da alle Besucher wirklich interessiert waren.

Da mein "Kuhboy" leider ein Tag vor der Abschlusspräsentation ausfiel (Der Display gab kein Lebenszeichen mehr von sich) und auch bei der Präsentation selber nicht funktionierte, konnte er leider nicht getestet und darauf gespielt werden.

Das Feedback konzentrierte sich vor allem auf das Design meines Gameboys, welches wiederholt als sehr süß bezeichnet wurde, und so wurde ich unter anderem auch gefragt, wie ich auf eine Kuh kam und ob denn auch Lautsprecher verbaut sind, sodass der Gameboy muhen kann :). Letztere Idee hätte ich im Nachhinein noch gerne umgesetzt.

### Ausblick

Im nächsten Semester von Sketching with Hardware steht das große Projekt im Mittelpunkt, für welches wir bereits jetzt Ideen sammeln sollen. Dem Projekt soll eine Problemstellung zugrunde liegen, welche wir im Projektprozess lösen sollen.
Hierbei können zum Beispiel Probleme aus dem Alltag Ideen schenken, egal ob die eigenen oder Probleme von Freunden und Bekannten:
- eine Erinnerungssystem, welches das bevorstehende Verlassen des Hauses registriert und zum Beispiel an Schlüssel oder noch offenstehende Fenster erinnert.

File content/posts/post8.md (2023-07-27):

---
title: "08 - Das 2. Semester"
date: 2023-07-11T12:16:27+02:00
show_reading_time: true
featured_image: "/media/haus_innen_cam_offen.jpeg"
draft: false
---

## Semesterverlauf

**Geplant vs Umgesetzt**

Das Semester startete damit, dass wir nach einer Einführung eine Projektidee finden mussten, die sowohl alle vorgestellten "Must Haves", sowie mind. einem "Should Have" entsprach. Ich entschied mich dazu, ein smartes Futterhäuschen zu bauen, welches nicht nur Fotos von Vögeln machen, sondern diese auch wiegen soll, während es als Futterhäuschen für diese dient. Die Bilder und Daten plante ich per Mail an den User zu verschicken.

Nach dem Projekt-Pitch, bei welchem jeder seine Idee einschließlich Zeitplan vorstellte, begann ich meine Projektarbeit zunächst damit, eine Teileliste mit allen benötigten Bauteilen aufzustellen und entwarf einen ersten Designentwurf, wie ich mir das Häuschen vorstellte.

{{< figure src="../media/projekt/hausdesign.png" width="60%" height="60%" caption="Erster Designentwurf mit Blender">}}

Für die Planung meines Projektes, sowohl was Zeitmanagment, als auch Dateiverwaltung betrifft, verwendete ich das Tool "Notion".
Mein Zeitplan sah folgendermaßen aus:

{{< figure src="../media/projekt/zeitplan.png">}}

Dieser stellte sich über das Semester hinweg als gut einhaltbar heraus. Getauscht wurden jedoch "Server Code" und "Häuschenfertigung".

Direkt zu Beginn recherchierte ich, welche Materialien ich bedenkenlos verwenden könnte, ohne die Sicherheit / Gesundheit meiner tierischen Besucher zu gefährden. Wie ich feststellte, ist Holz hierbei die beste Wahl. Dieses sollte jedoch für Wetterbeständig- und Langlebigkeit lasiert werden. Dafür wird Lasur auf Wasserbasis empfohlen, da sie als weniger umweltbelastend gilt. Auf folgende Materialien sollte auf jeden Fall verzichtet werden: Materialien mit Zink oder Schwermetalle, die rosten. Rost, Zink und Schwermetalle sind giftig für Vögel.

Während die Bestellung der Bauteile noch unterwegs ins Lab war, änderte ich meinen Plan für das Versenden der Bilder und Daten und setzte schonmal den Server auf, an welchen mein Vogelhäuschen die Daten senden sollte, statt sie per Mail dem User zugänglich zu machen. Dabei entschied ich mich für Node.Js mit dem Framework Express aufgrund der großen Vereinfachung beim Coden, die das Framework bot.
Des Weiteren modellierte ich bereits ein 3D-Modell eines Case für den Gewichtssensor, der die Wiegefunktion des Häuschens umsetzen sollte. 

{{< figure src="../media/projekt/modell_sensorcaseunten.png"  width="60%" height="60%" caption="Unterer Teil des Sensor-Cases">}}
{{< figure src="../media/projekt/modell_waagblatt.png"  width="60%" height="60%" caption="Bewegliches Zwischenblatt">}}
{{< figure src="../media/projekt/modell_sensorcaseoben.png"  width="60%" height="60%" caption="Oberer Teil des Sensor-Cases">}}

Das Modell musste jedoch angepasst und ein Weiteres mal gedruckt werden, da eine Bohrung für eine Schraube zur Befestigung des Gewichtssensors im Case nicht an der passenden Stelle saß.

Um die ESP32-Cam, die ich als Modul für das Bildermachen wählte, möglichst stromsparend zu nutzen, plante ich, den Gewichtssensor als Interrupt-Auslöser zu verwenden und den ESP, solange der Gewichtssensor keine Schwankung in seinen Messungen feststellte, in einen light sleep zu versetzen. Als der Sensor jedoch ankam und ich ihn testen konnte, stellte ich fest, das dieser Plan nicht umzusetzen war. Da der Sensor durch seinen digitalen Output eine serielle Verbindung zum ESP aufbaut und konstant Daten sendet, wurde bei den Tests ein Interrupt nicht nur bei Schwankungen in den Messungen, sondern stattdessen durchgehend ausgelöst. Ich konnte nun zwischen zwei Alternativen wählen:
- Das Problem software-seitig lösen: Das heißt, im Code konstant überprüfen, ob das Gewicht auf dem Sensor steigt, und ab einem bestimmten Gewicht das Foto machen und an den Server senden. Nachteil: keine energie-effiziente Verwendung des ESP. Vorteil: keine zusätzlichen Bauteile nötig, einfach umzusetzen.
- Eine andere Möglichkeit finden, einen Interrupt auszulösen, wenn ein Vogel da ist, zum Beispiel mit einem weiteren Sensor.

Ich entschied mich für letzteres und baute einen Vibrationssensor in das Häuschen mit ein, welcher auf Erschütterungen der Futterschale vor dem Häuschen reagiert, sprich, wenn zum Beispiel ein Vogel Futter von der Schale pickt.

**Fertigungsverfahren**

Beim Bau des Häuschens setzte ich verschiedene Fertigungsverfahren ein. Für die Gehäuse für die technischen Module verwendete ich den 3D-Drucker. Hierbei gefiel mir, dass auf Millimeter genau alles vermessen und angefertigt werden konnte. Mit einem guten Modell ist man nach dem Design von diesem fertig und muss es am Ende nur noch aus dem Drucker holen. Jedoch gab es zum einen in der Praxis sehr oft Probleme mit den Druckern und die Modelle kamen oft nicht so raus wie geplant. Zum Anderen war für mich ein großer Nachteil, dass die Modelle im Nachhinein kaum bearbeitbar waren. Sprich bei Planänderungen (wie zusätzlich verwendeten Schrauben, anderer Kabelführung o.Ä.) hieß dies direkt, das ganze Modell neu zu drucken. 

Das restliche Haus baute ich aus verschiedenen Holzplatten zusammen, die ich mit Band- bzw. Stichsäge auf die passenden Größen zurecht schnitt. Mit Holz zu arbeiten hat mir wesentlich besser gefallen, da auch noch im Nachhinein Stellen durch zB. Feilen angepasst werden konnten.

**Motivation und Evaluation**

Die größte Motivation für das Semester war das eigene Projekt. Dadurch, dass ich mir selbst ausgesucht habe, welches Projekt ich machen will und dieses auch nach meinen Vorstellungen umsetzen konnte, war die Motivation größer, das Projekt auch fertigzustellen.

Mit dem Kurs habe ich nicht nur festgestellt, wie viel Spaß mir nicht nur das softwareseitige Erarbeiten von Projekten macht, wie es für mich bisher im Informatik Studium der Fall war, sondern auch am Bau der Hardware beteiligt zu sein. Auch die Fertigung und Holzarbeit hat mir wesentlich mehr Spaß bereitet als gedacht und ich habe viele neue Methoden gelernt. Für mich privat nehme ich davon mit, nun auch allein dazu in der Lage zu sein, ähnliche Projekte unabhängig vom Studium in der Freizeit umzusetzen. Auch für meine berufliche Zukunft ist es sicherlich von Vorteil, diese Verknüpfung von Software und Hardware gelernt zu haben.

Das Modul und die Projektarbeit haben mir sehr gut gefallen und wir wurden angemessen betreut und unterstütz, so dass wir bei größeren Probleme nicht allein gelassen wurden und "festsaßen", sondern mit ein wenig Unterstützung weiter voran kamen.
Für zukünftige Kurse würde ich mir neue 3D-Drucker wünschen, um die Arbeit zu erleichtern. Bei den Lötkolben wurden bereits Spitzen ersetzt, was sehr geholfen hat. Außerdem würde ich mir etwas mehr Zeit wünschen, da es bei einigen trotz Zeitplan ziemlich knapp wurde und auch ich nur ein paar Tage vorher ganz fertig wurde. Man könnte zum Beispiel früher im Semester mit der Projektarbeit anfangen, der Projekt-Pitch fand bei uns erst Mitte Mai statt, einige Wochen nach Semesterstart.

{{< rawhtml >}} 
    <br>
{{< /rawhtml >}}
## Das Projekt: Bird Booth
{{< figure src="../media/projekt/Poster_AnnaMarburger.png" caption="Poster für das Streiflicht 2023 ">}}

Bird Booth sollte ein smartes Futterhäuschen werden mit der Funktion, Bilder zu machen, wenn ein Vogel an die Futterstelle kommt und diesen zu wiegen, um anschließend die Daten an einen Webserver zu senden. Das Futterhäuschen sollte sicher für Vögel, wetterbeständig und robust werden.

**Features**

{{< figure src="../media/projekt/schaltplan.png" caption="Komponenten-Schaltplan ">}}

- **Kamera:** Das Häuschen hat eine eingebaute Minikamera im Inneren, die auslöst, wenn eine Erschütterung auf der Futterschale wahrgenommen wird. Letzteres geschieht durch einen Vibrationssensor. Die Kamera wird durch eine ESP32-Cam implementiert. Der Microchip wartet also auf ein Signal des Vibrationssensor und sendet, sobald dieses eintrifft ein Foto an einen Server.
- **Waage:** Nicht nur ein Bild wird an den Server geschickt, sondern auch das Gewicht, dass der Gewichtssensor unter der Sitzstange des Häuschens misst. Die Mechanik im Gewichtssensor-Case erlaubt eine sensible Messung: Setzt sich ein Vogel auf die Sitzstange, so überträgt diese das Gewicht auf das Zwischenblatt im Case. Dieses widerum leitet das Gewicht auf die nicht befestigte Seite des Gewichtssensors weiter. Dadurch dehnt sich dieser minimal nach unten. Um die gemessenen Daten lesen zu können, da der Gewichtssensor das Gewicht über sogenannte Dehnungsmessstreifen wahrnimmt und dadurch sehr kleine Messungen zurückgibt, wird ein Amplifier benötigt.
- **Mobilität:** Damit das Häuschen draußen montiert werden kann, wird eine mobile Stromversorgung in Form von 3x AAA-Batterien verwendet. Das Batterie-Case befindet sich im “Keller” des Häuschens, geschützt von äußeren Einflüssen.
- **Webserver:** Um die Bilder und Gewichtsdaten einsehen zu können, steht ein eigener Server bereit. Dieser verwendet Firebase Storage als Datenbank zum Speichern der Daten. So kann der User von überall und von allen Geräten auf die Daten zugreifen. Der Server wurde mit Node.js Express geschrieben. Das Framework ermöglicht unkomplizierten Code und kann so mit relativ wenig Vorwissen ebenfalls angepasst werden. Über den Server können die Bilder auch heruntergeladen oder wieder gelöscht werden. Auch können die Bilder nach gemessenem Gewicht sortiert und die Ansicht auf Bilder, die “heute” oder auch “diese Woche” entstanden sind, eingeschränkt werden.
- **Zugänglichkeit:** die technischen Komponenten sind leicht zugänglich und so können Anpassungen bzw. das Ersetzen von Modulen leicht durchgeführt werden.
- **Stromsparend:** Damit die Batterien möglichst lange durchhalten und nicht so oft gewechselt werden müssen, wurde der Code für das ESP-Modul so geschrieben, dass er in einem stromsparenden sleep-modus fällt, wenn keine Vögel detektiert werden. Im sogenannten “light-sleep” kappt der ESP beispielsweise WLAN-Verbindungen. Der größte Teil des RAM und der CPUs werden jedoch taktgesichert und können nach dem aufwachen ihren Betrieb wieder aufnehmen, da ihr innerer Zustand erhalten bleibt.

Folgendes Diagramm veranschaulicht die Funktion / Ablauf des Futterhäuschens:

{{< figure src="../media/projekt/ablaufdiagramm.png" caption="Ablaufdiagramm">}}

Alle Features waren zum Zeitpunkt der Abschlusspräsentation bereits geplant und ebenso voll funktionsfähig. Nach der Präsentation wurde nichts mehr an dem Projekt verändert.

{{< rawhtml >}} 
    <br>
{{< /rawhtml >}}
## Gallerie

**Häuschen**
  \
  \
{{< rawhtml >}} 
    <video width=80% controls autplay >
        <source src="../media/projekt/haus.mp4" type="video/mp4">
        Your browser does not support the video tag.  
    </video>
{{< /rawhtml >}}
  \
  \
{{< rawhtml >}} 
    <video width=80% controls autplay >
        <source src="../media/projekt/haus_zugaenglichkeit.mp4" type="video/mp4">
        Your browser does not support the video tag.  
    </video>
{{< /rawhtml >}}
  \
  \
{{< figure src="../media/projekt/fertigeshaus.jpg" caption="Fertiges Häuschen von Vorne">}}
  \
{{< figure src="../media/projekt/keller.jpeg" caption="Kellerfach und Futterschale">}}
  \
{{< figure src="../media/projekt/gewichtssensor.jpeg" caption="Gewichtssensor-Case mit Sitzstange">}}
  \
{{< figure src="../media/projekt/dach.jpeg" caption="Schornstein / Dach von Innen ">}}
  \
{{< figure src="../media/projekt/haus_innen_cam.jpeg" caption="Haus von Innen (Sicht auf ESP)">}}
  \
  \
**Server**
  \
{{< figure src="../media/projekt/server_desktop.png" caption="Screenshot Desktopansicht">}}
  \
{{< figure src="../media/projekt/server_iphone.png"  width="60%" height="60%" caption="Screenshot IPhone X">}}

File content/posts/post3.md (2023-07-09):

---
title: "03 - Microcontroller Labor"
date: 2022-12-04T18:42:03+01:00
featured_image: "/media/lab2_ledmatrix.jpeg"
show_reading_time: true
draft: false
---

Es fanden drei Microcontroller Labortage statt, von denen ich an einem aufgrund von Krankheit nicht teilnehmen konnte.

### Tag 1
Am ersten Tag erhielten wir zunächst eine Kiste mit verschiedenen Bauteilen. In der Runde besprachen wir verschiedene Sensoren, wie zum Beispiel für Luftfeuchtigkeit oder Temperatur. 
Anschließend programmierten wir unseren ersten Arduino mit dem Beispielprogramm "Blink" der Arduino IDE. 

Nachdem die eingebaute Mini-LED im Arduino erfolgreich blinkte, schlossen wir mit Hilfe einer Steckplatine externe LED's an und passten auch dementsprechend das Skript für den Arduino an. 

{{< figure src="../media/lab2_ledblinken.gif"  width="60%" height="60%">}}

Anschließend durften wir mit den verschiedenen Sensoren herumbasteln. 
Mit einem Touchsensor probierte ich, eine LED durch diesen zum Leuchten zu bringen, bzw. wieder auszuschalten. Leider reagierte der Sensor nicht besonders gut und wurde deshalb schnell durch einen normalen Button ersetzt. Danach funktionierte das Skript einwandfrei.

Des Weiteren entschlossen wir zu Zweit, mit einem Motor ein Ventilatorähnliches Bauteil zum Drehen zu bringen. Nachdem es zuerst zwei Mal kaputt ging, da die Drähte sich lösten, und gelötet werden musste, verkabelten wir es mit einem Arduino. Leider bedachten wir nicht, dass der Arduino nicht in der Lage dazu war genügend Strom für dieses Bauteil zu liefern. So beendeten wir dieses Projekt nicht erfolgreich, da am Ende für die etwas kompliziertere Lösung die Zeit fehlte.

### Tag 2

An diesem Tag verpasste ich leider das Labor und konnte so an keinem Miniprojekt weiterarbeiten. In der Vorlesung wurden am diesen Tag unter anderem das Schema der serielle Kommunikation besprochen.

### Tag 3

Nach einer einführenden Vorlesung,in der unser Wissen vor allem zu Output abgerundet wurde, durften wir wieder mit den verschiedenen Bauteilen basteln. Ich entschied mich dazu, mehrere LED Matrizzen aneiander zu schließen. Mit einer Bibliothek versuchte ich verschiedene Textausgaben darstellen zu lassen. Dies funktionierte jedoch nicht, auf den Matrizzen war kein Text zu sehen. Zudem störte ein massiver Wackelkontakt etweder bei den Kabeln oder bei den LED Matrizzen das Ergebnis. Das eigentliche Ziel war, animierten Text darzustellen, z.B. ein Wort, dass die Matrix einmal quer "durchläuft". 

{{< figure src="../media/lab2_ledmatrix.jpeg"  width="60%" height="60%">}}

Ohne die Bibliothek war dies mit meinen Fähigkeiten leider nicht möglich und so beschränkte sich das Ergebnis auf ein paar hardgecodete leuchtende LED's der Matrix.

### Interrupts und Sleep-Modi

Um einen Arduino Stromsparend zu verwenden, gibt es verschieden Sleep Modi und Interrupts, um z.B. eine möglichst lange Akkulaufzeitt zu bekommen.

##### Interrupts
 Ein Interrupt ist ein Mechanismus der zur Überwachung von Echtzeitevents genutzt wird. Dabei funktioniert er folgendermaßen:
 Wird ein bestimmtes Signal festgestellt, unterbricht der Interrupt die aktuelle Handlung des Prozessors und führt für diesen Fall zuvor festgelegten Code aus. Anschließend kehrt der Prozessor zum vorherigen Punkt zurück und setzt seine unterbrochene Handlung fort.
 Ein großer Vorteilist folglich, dass aktives Warten des Prozessors vermieden wird, gleichzeitig aber auf Events in Echtzeit reagiert werden kann.

 Um dies im Code umzusetzen, gibt es folgende Methode

 ``` arduino
    void setup() {
        // Attach an interrupt to the ISR vector
        attachInterrupt(0, interruptMethod, CHANGE);
    }

    void interruptMethod() {
        //do interrupt action here
    }
```

Die attachInterrupt() nimmt drei Parameter:
- Den Interrupt Vektor, der festlegt, von welchem Pin ein Interrupt generiert werden kann. Jedoch ist dies hier nicht die Nummer des Pins selbst, sondern eine Referenz auf eine Stelle im Speicher. Für Arduinos ist der Vektor 0 für Pin 2 und Vektor 1 für Pin 3 (Anmerkung: Es können nicht alle Pins Interrupts auslösen).
- Der Name der Methode, die bei einem Interrupt ausgeführt werden soll.
- Der Interrupt Modus. Er bestimmt, welche Pin-Aktion einen Interrupt auslöst. Es gibt dabei die Modi 'RISING, FALLING, CHANGE, LOW' (Funktion dem Name entsprechend)

In obigem Beispiel wird also Pin 2 auf jede Wertänderung überwacht, um bei eintreffendem Interrupt die Methode interruptMethod() aufzurufen.

##### Sleep Modi

Während Interrupts also aktives Warten vermeiden lassen, können Sleep Modi dazu dienen, den Prozessosr bzw. Teile davon in einen inaktiven Zustand zu versetzen.

Um den Sleep Modus ein- bzw. auszuschalten gibt es folgende Funktionen:

``` arduino
    set_sleep_mode(SLEEP_MODE_PWR_DOWN);
    sleep_enable(); // sleep mode einschalten
    sleep_mode(); // in den sleep mode gehen
    sleep_disable(); // sleep mode ausschalten nach Erwachen
```

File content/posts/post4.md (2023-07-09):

---
title: "04 - Mechanik Labor"
date: 2023-01-23T13:50:18+01:00
show_reading_time: true
featured_image: "/media/mech_titel.jpeg"
draft: false
---

Im heutigen Labor ging es um Mechanik. In der Vorlesung wurden die verschiedenen grundlegenden Ideen von Maschinen erklärt: Energie umwandeln oder übertragen, Kraft vervielfachen oder umlenken und Geschwindigkeit erhöhen. Die daraus entstandenen mechanischen Prinzipien beruhen auf:
- Hebel
- Flaschenzüge
- Rad + Achse
- geneigte Fläche
- Gewinde sowie
- Zahnräder

Beispielsweise wird bei Alltagsgegenständen wie dem Flaschenöffner oder der Schere die Hebelwirkung genutzt.

Anschließend wurden Baukits ausgeteilt, mit welchen wir verschiedene Mechanismen zu zweit nachbauen durften.

Als erstes bekamen wir die Aufgabe, ein einfaches Getriebe zu bauen:

{{< figure src="../media/mech_getriebe.jpeg"  width="60%" height="60%">}}

{{< figure src="../media/mech_getriebe.gif"  width="60%" height="60%">}}

Außerdem bauten wir ein 3-Gang-Schaltgetriebe:

{{< figure src="../media/mech_3gang_1.jpeg"  width="60%" height="60%">}}

{{< figure src="../media/mech_3gang_2.gif"  width="60%" height="60%">}}

Hier bereitete das exakte Einstellen der Zahnräder, so dass diese passgenau ineinander greifen, zunächst Schwierigkeiten. Am Ende ließ sich das Getriebe jedoch nahezu mühelos umschalten.

Zusätzlich steckten wir einen Scherenhub:

{{< figure src="../media/mech_hebeplatte.gif"  width="60%" height="60%">}}

Sowie zum Schluss das sogenannte Planetengetriebe (Umlaufrädergetriebe):

{{< figure src="../media/mech_planetengetriebe.gif"  width="60%" height="60%">}}

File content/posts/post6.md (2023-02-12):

---
title: "06 - Additive Fertigung"
date: 2023-02-12T14:08:27+01:00
featured_image: "/media/lab4_qboydruck.jpeg"
show_reading_time: true
draft: false
---

Im Gegensatz zur subtraktiven Fertigung, die Thema des letzten Labors war, werden bei der additiven Fertigung durch Hinzufügen von Material Teile hergestellt. Dies kann beispielsweise durch einen 3D-Drucker geschehen. Hierbei gibt es verschiedene Arten an Druckern:
- SLA: Stereolithography
- FDM: Fused Deposition Modeling
- SLS:  Selective Laser Sintering
- SPD:  Selective-Powder-Deposition

In unserem Labor stehen FDM Drucker zur Verfügung. Bei diesen Druckern wird Material erhitzt und aus einer Nozzle am Druckkopf gepresst, um so Schicht für Schicht das gewünschte Modell auf einer Platte aufzubauen. Es gibt zwei gängige Architekturen bei Druckern dieser Art:
- "Bowden tube extrusion system": Der Extruder befindet sich gesondert von Druckkopf und Nozzle. Vorteile: schneller und genauer, da der Druckkopf nicht durch den Extruder beschwert wird
- "Direct-Drive-Extruder": Der Extruder sitzt direkt am Druckkopf. Vorteile: Einfacher Materialwechsel, kann flexible Materialien drucken (da sich diese nur "ziehen" und nicht "schieben" lassen).

Als Material kann zwischen verschiedenen Plastikarten wie PLA, PETG, ABS, TPU und PVE gewählt werden, je nach gewünschten Eigenschaften (zB. flexibel vs. stabil). Je nach Material muss eine unterschiedliche Temperatur bei Druckbett und Extruder gewählt werden. 

#### Software

Zum Erstellen eines 3D-Objekts kann sowohl CAD Software, wie Autodesk Fusion 360, aber auch Mesh-Bearbeitungssoftware wie zum Beispiel Blender genutzt werden. Mit ersterem lassen sich 3D-Modelle auf exakte Maßangaben hin durch geometrische Modellierung erstellen und drucken. Es wird dabei direkt mit 3D-Körpern gearbeitet und nicht mit Meshes, wie es bei Software wie Blender o.Ä. der Fall ist. Letzteres eignet sich demnach für komplexere Objekte mit freien Formen.
Im Lab bekamen wir die Aufgabe, eine Papierhalterung zu designen:

{{< figure src="../media/infoschild.png" >}}

Anschließend muss erstelltes 3D-Objekt, exportiert als ".stl"-Datei, gesliced werden. Dies passiert durch eine weitere Software, in unserem Fall "UltiMaker Cura". Beim slicen wird entsprechendes Objekt in Anweisungen für den 3D-Drucker übersetzt. Außerdem können Einstellungen wie
- Extrusionsbreite, 
- Geschwindigkeit, 
- Supportstrukturen und 
- Füllung 

beeinflusst werden. Die "geslicte" Datei wird anschließend dem 3D-Drucker übergeben und das 3D-Objekt gedruckt.

#### Typische Fehler beim 3D-Druck:
- Unglatter Druck, klar sichtbare Linien. Grund: Billiges Material, oder auch zu hohe Layer Höhe / Temperatur.
- Stringing, der Drucker zieht ungewollte Fäden. Grund: Zu hohe Temperatur, zu geringer Rückzugabstand / Druckgeschwindigkeit, aber auch bestimmte Materialien.
- Wölben des Materials an Ecken. Grund: Zu hohe Drucktemperatur, zu wenig Kühlung während des Drucks.

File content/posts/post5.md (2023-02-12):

---
title: "05 - Subtraktive Fertigung"
date: 2023-01-23T13:51:30+01:00
featured_image: "media/lab3_bojackergebnis.jpeg"
draft: false
show_reading_time: true
---

### Eigenschaften und Materialien

Subtraktive Fertigungsmethoden werden verwendet, um durch Entfernen von Material Teile anzufertigen. Dies kann z.B. durch Bohren, Fräsen, Schleifen und Schneiden geschehen. Typische Geräte, die dazu verwendet werden, sind zum Beispiel die Drehmaschine, die CNC-Fräse und der Laser Cutter. Bei Letzterem ist darauf zu achten, dass keine Materialien verwendet werden, bei deren Bearbeitung giftige Gase entstehen. Ein Beispiel dafür ist (Kunst-)leder (mit Chrom) oder Teflon. Hingegen können folgende Materialien problemlos eingesetzt werden:
- CNC-Fräse: Thermosetkunststoffe, Harte Thermoplaste
- Laser-Cutter: Metalle, Holz, Acrylglas, Stoff

Außerdem können auch Metalle bei beiden Fertigungsverfahren bearbeitet werden, dazu sind jedoch industrielle Anlagen nötig und die Geräte in unserem Lab nicht geeignet.

### Projektplanung

Bei meinem Projekt soll, wie in der nachfolgenden Skizze zu sehen ist, der untere sowie obere Teil des GameBoys mithilfe subtraktiver Fertigungsverfahren hergestellt werden. Dazu soll die Kuhform zwei Mal aus einer Holzplatte geschnitten werden. Zusätzlich soll dann in den oberen Teil (den "Deckel") das Design gelasert werden wie zum Beispiel Augen und Kuhflecken. Für Display und Knöpfe müssen des Weiteren passende Löcher in die obere Platte gefräßt werden. Abschließend soll aus einer weiteren, dünneren Holzplatte die Mähne der Kuh ausgeschnitten werden, um diese am Ende auf die Vorderseite des GameBoys kleben zu können und dadurch das Design zu vervollständigen.

{{< figure src="../media/QBoySkizze_vorne.jpeg"  width="80%" >}}
{{< figure src="../media/QBoySkizze_seite.jpeg"  width="80%" >}}

### Labortag-Fertigung

Um das Laser Cutten auszuprobieren, bekamen wir die Möglichkeit, ein 5x5 cm Teil anzufertigen. Dazu wählte ich folgendes Design:

{{< figure src="../media/lab3_bojackdesign.png"  width="60%" height="60%">}}

Die SVG-Datei lud ich in das LightBurn Programm und passte die Größe so an, dass es auf eine ca 5x5 cm Holztafel passte. Anschließend wurde das Design in 3 Durchläufen auf die Holzplatte gelasert, in welchen schrittweise der Power-Wert höher gestellt wurde, während der Wert für die Speed Einstellung verringert wurde, bis das Design ausreichend sichtbar auf dem Holz wurde. Das Ergebnis ist in folgendem Bild zu sehen:

{{< figure src="../media/lab3_bojackergebnis.jpeg"  width="60%" height="60%">}}

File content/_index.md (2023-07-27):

---
title: "Sketching with Hardware I + II"

description: "Blog des Anwendungsfachs Sketching With Hardware an der Universität Ulm - WS 2022/23 und SS2023 -"
featured_image: "/media/hero.jpeg"
# 1. To ensure Netlify triggers a build on our exampleSite instance, we need to change a file in the exampleSite directory.
theme_version: '2.8.2'
 
---

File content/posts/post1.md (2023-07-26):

---
title: "01 -  Vorstellung"
date: 2022-11-03T13:58:40+01:00
show_reading_time: true
draft: false
---

### Vorstellung
Mein Name ist Anna und ich studiere im 5. Semester Medieninformatik. In diesem Semester ist es vorgesehen, ein Anwendungsfach zu belegen und ich wählte, durch ein Plakat in den Unigängen überzeugt, Sketching With Hardware. Durch meinen Opa angeleitet, der sich selbst als leidenschaftlicher "Bastler" bezeichnete, verbrachte ich schon als kleines Kind immer wieder Zeit im Bastelkeller. Leider noch zu jung, um wirklich mithelfen zu dürfen, aber das Zuschauen machte auch Spaß. 

### Erwartungen

In meinem Studium hatte ich bisher lediglich die Möglichkeit, meine Fähigkeiten im Software Bereich zu vertiefen. So freue ich mich darauf, in Sketching with Hardware zu lernen, Projekte nicht nur auf Software Ebene selber umzusetzen, sondern auch die nötige Hardware eigenständig herzustellen. Konkret erwarte ich von dem Modul, verschiedene, für mich neue, Techniken wie Löten, 3D-Druck etc. zu lernen und nach dem Kurs in der Lage zu sein, vollständige (kleine) Projekte umsetzen zu können.

### Alle Fähigkeiten - welches Projekt?

Um den schweren Alltag als Studentin besser tragen zu können, wäre meine erste Projektwahl, wenn ich alle nötigen Fähigkeiten hätte, wohl der Bau eines Kaffeevollautomaten. Einen solchen in der Küche stehen zu haben, wer träumt nicht davon? Jedoch das Geld dafür hinzublättern fällt direkt schwerer. Der Kompromiss: Selber bauen und dabei hoffentlich einiges einsparen.

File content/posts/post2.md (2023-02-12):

---
title: "02 -  E-Technik Labor"
date: 2022-11-11T18:15:06+01:00
featured_image: "media/lab1_loeten_vorgang.png"
show_reading_time: true
draft: false
---

Nach einer einführenden Vorlesung zu Elektrotechnik, in der unser Wissen zu Strom, Spannung und Widerstand aufgefrischt wurde, bildete der erste Versuch des heutigen Labs das Löten.

### Versuch 1: Löten

In Zweierteams wurden uns Lötkolben, Lötzinn, Entlötlitze und Flussmittel bereitgestellt, sowie eine Leiterplatte und verschiedene Widerstände. 

{{< figure src="../media/lab1_loeten_zubehoer.png"  width="60%" height="60%">}}

Letzere sollten also auf der Platte festgelötet werden. Zunächst musste dafür das Flussmittel auf die zu lötende Stelle aufgetragen werden. Anschließend wurde die Stelle mit dem Lötkolben erhitzt und der Lötzinn daran gehalten, bis dieser flüssig wurde. Nach dem Erhärten war die Stelle auch schon erfolgreich verlötet.

{{< figure src="../media/lab1_loeten_vorgang.png"  width="60%" height="60%">}}

Da ich bisher noch keine Erfahrungen mit Löten sammeln konnte, war der Start zunächst holprig - nach zwei, drei Mal löten klappte es jedoch bereits gut.

{{< figure src="../media/lab1_loeten_ergebnis.png"  width="60%" height="60%">}}

### Versuch 2: Messgeräte im Labor

#### 2.1 Einführende Aufgaben

Um das Wissen aus der vorangegangenen Vorlesung zu festigen und auf den folgenden Versuch zu Messgeräten im Labor vorzubereiten, beschäftigten wir uns als nächstes mit ein paar Aufgaben zum Ohmschen Gesetz, Kennlinien und zur Leistung. So sollten wir Widerstände berechnen, von Kennlinien ablesen und Zusammenhänge zwischen Strom- und Widerstandgrößen bzw der Leistungsabgabe verstehen.

#### 2.2 Messen mit dem Multimeter

Vorbereitung: Anschließen eines Widerstandes an das Labornetzteil nach folgendem Schema:

 {{< figure src="../media/lab1_messen_schema.png" caption="" width="60%" height="60%">}}

Vorgehen: Ein Multimeter schlossen wir parallel zum Widerstand an, um die Spannung zu messen, sowie ein weiteres in Reihe, um den Strom zu messen. Letzteres war nötig, da die Stromangaben des Labornetzteils etwas ungenau waren. 

Ergebnisse: Es wurden 10 Strom- bzw. Spannungswerte gemessen, die wir in folgende Tabelle vermerkten.

{{< figure src="../media/lab1_messtabelle.png" caption=""  width="60%" height="60%">}}

Dies ergab folgende Kennlinie für den Widerstand:

{{< figure src="../media/lab1_kennlinie.png" caption=""  width="65%" height="65%">}}

Bei die Berechnung des Widerstands fallen die Messungenauigkeiten und -fehler des Versuchs durch die leichten Schwankungen der Angaben auf.

In der Schule behandelte der Physikunterricht das Messen mit dem Multimeter, so war dies für mich zwar nicht neu; Da die letzte Physikstunde jedoch schon eine ganze Weile her ist, frischte dieser Versuch mein Wissen dazu deutlich auf.

#### 2.3 Widerstand mit dem Spannungsteiler bestimmen

Der letzte Versuch bildete das Messen eines Widerstands mit einem Spannungsteiler.

Vorgehen: Zunächst musste dafür ein Spannungsteiler gebaut werden, dies realisierten wir mit Hilfe einer Steckplatte.

{{< figure src="../media/lab1_stromteiler_aufbau.png" width="60%" height="60%">}}

Anschließend nahmen wir die Werte der Spannung des zweiten Widerstandes bzw. der gesamten Spannung. Zudem maßen wir den Wert des zweiten Widerstandes. 
Vorteil der Berechnung des Widerstandes durch die Formel aus der Vorlesung ist klar, dass keine Stromwerte gemessen werden müssen.

### Projektentscheidung: GameStation

Als Projekt für das erste Semesteron Sketching with Hardware entscheide ich mich für die RetroPie GameStation.

{{< figure src="../media/gamestation_skizze.png" caption=""  width="65%" height="65%">}}

Dafür habe ich folgenden Steckplan mit Hilfe der Fritzingsoftware gebaut:

{{< figure src="../media/gamestation_loetplan.png" caption=""  width="65%" height="65%">}}

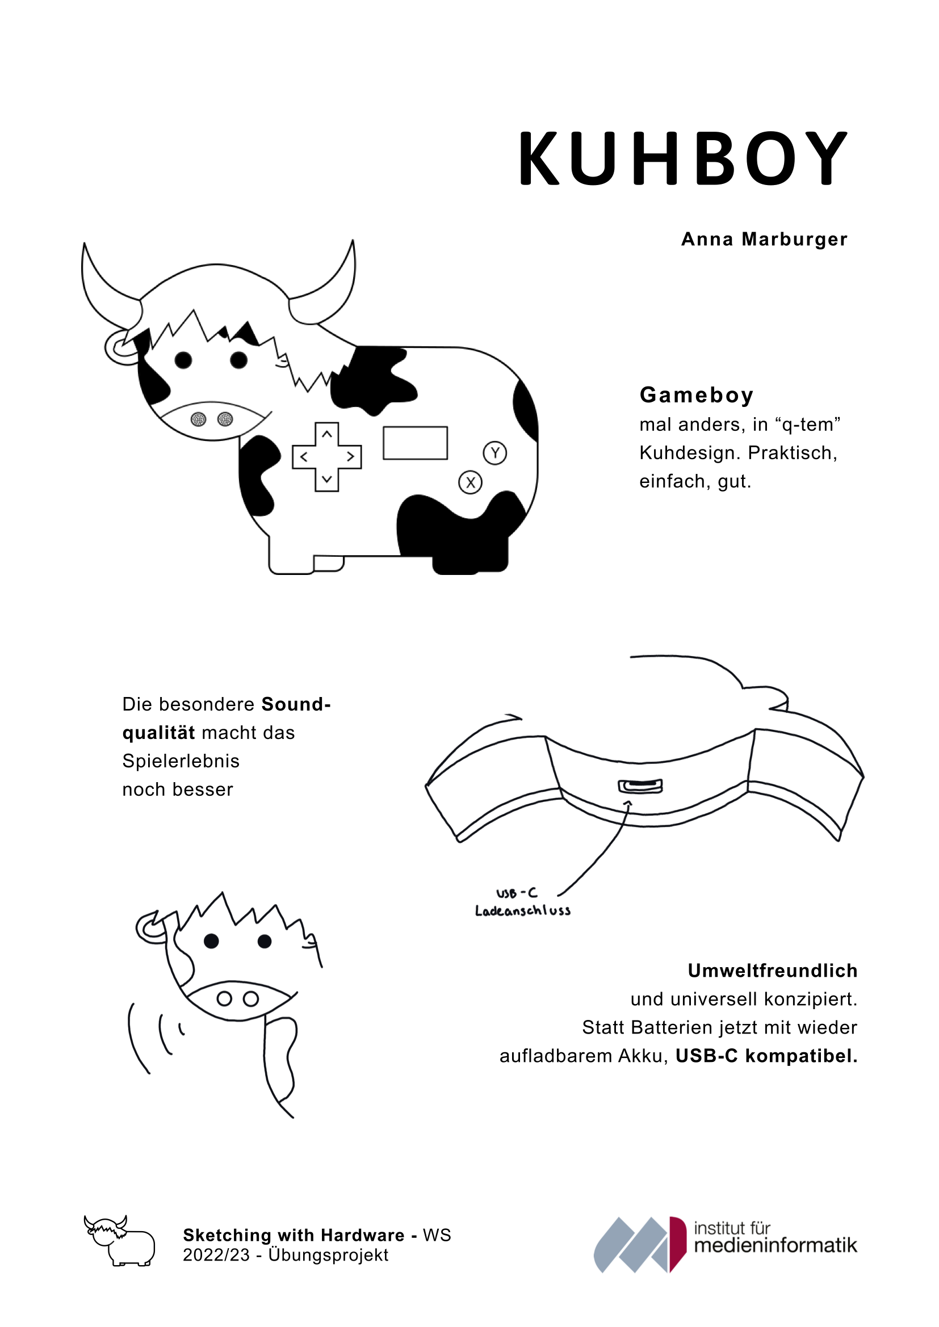
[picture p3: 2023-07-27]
content/posts/media/Poster_QBoy.png

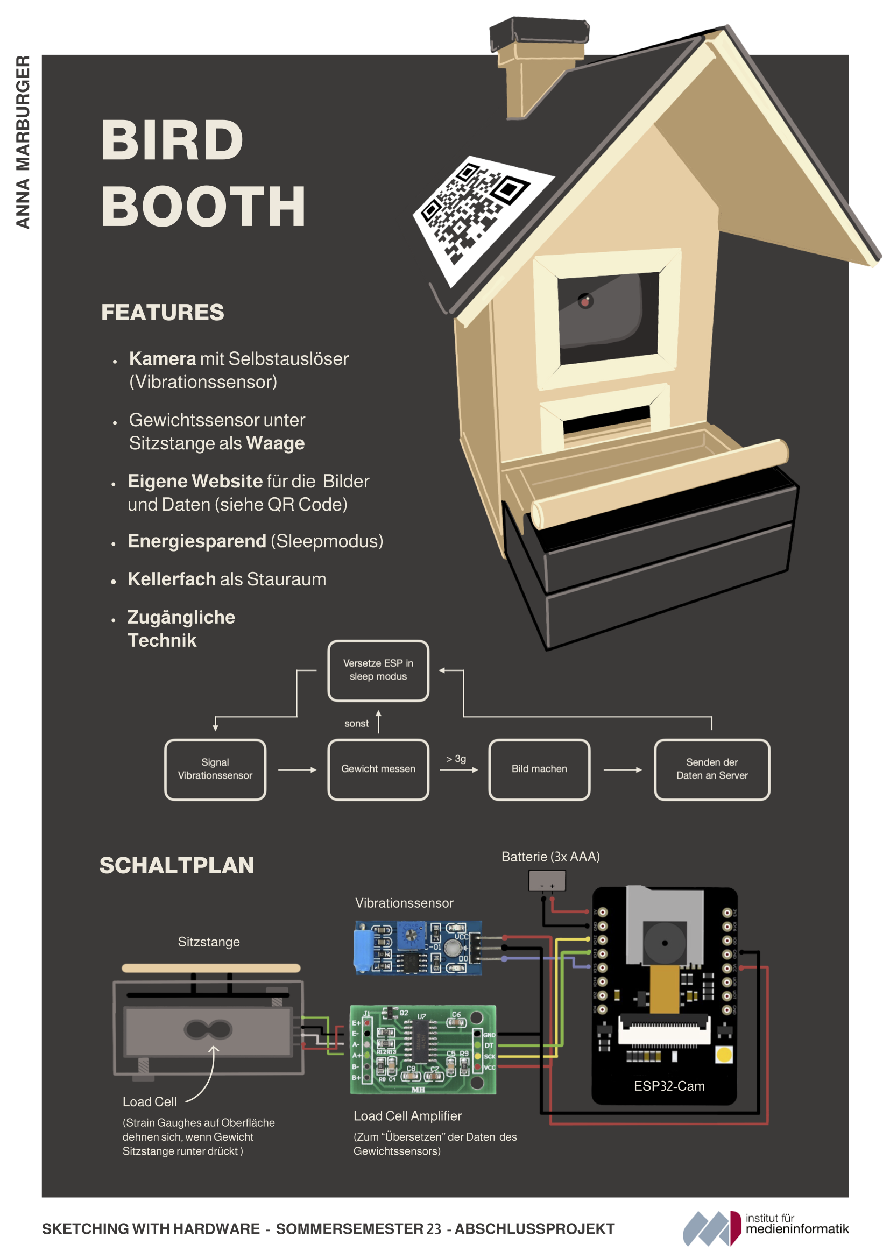
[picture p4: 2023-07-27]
content/posts/media/projekt/Poster_AnnaMarburger.png

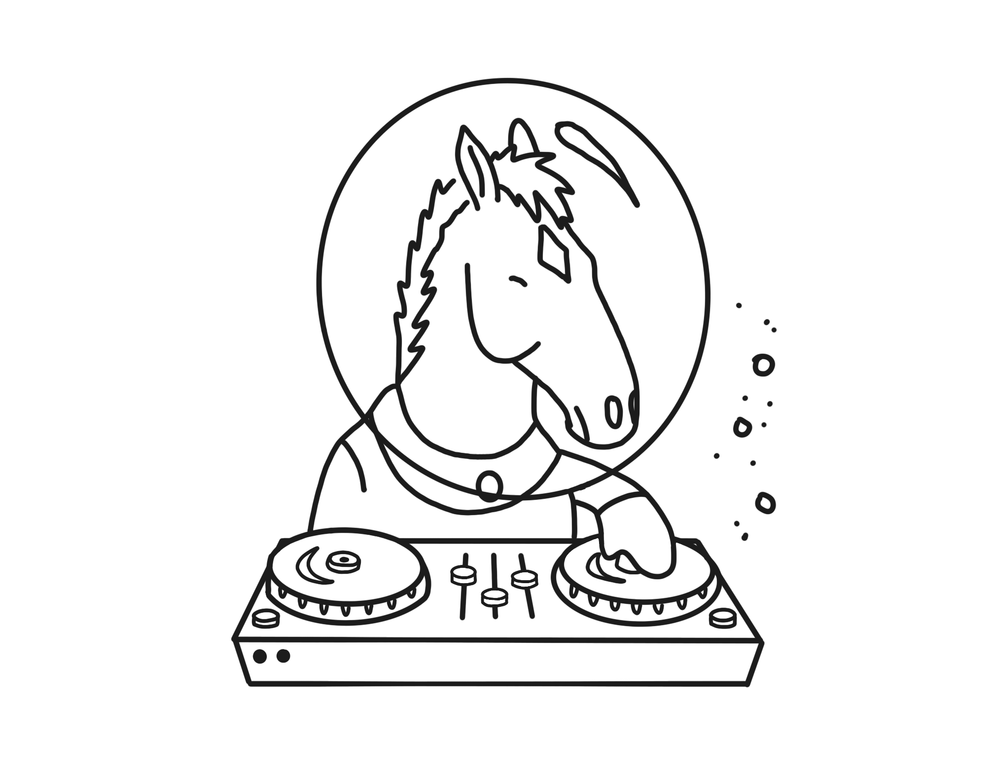
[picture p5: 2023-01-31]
static/media/lab3_bojackdesign.png

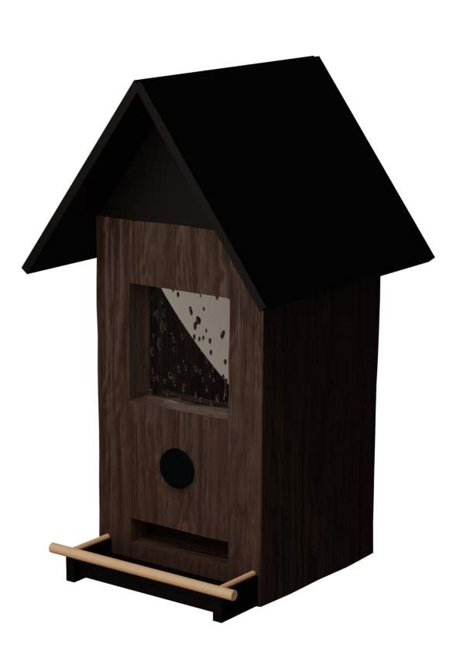
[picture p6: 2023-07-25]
content/posts/media/projekt/hausdesign.png

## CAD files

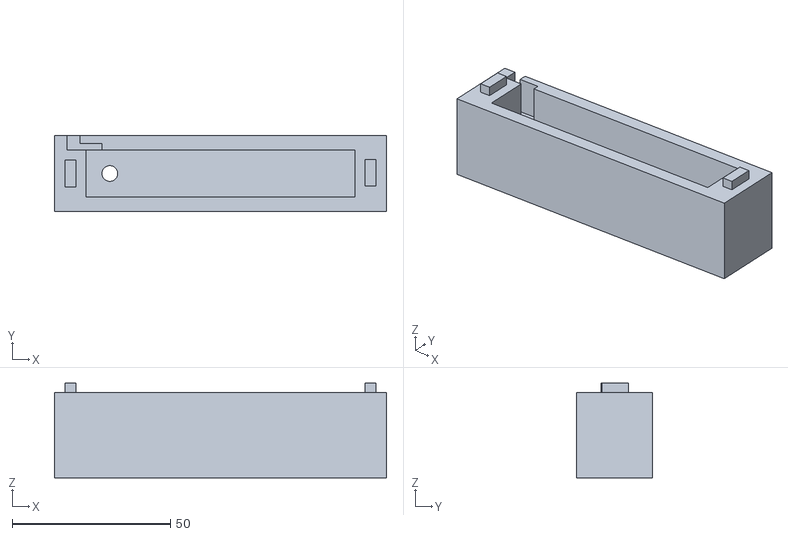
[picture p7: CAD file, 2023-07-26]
birdbooth_files/sensorcase_unten.stl
105.0 x 24.0 x 30.0

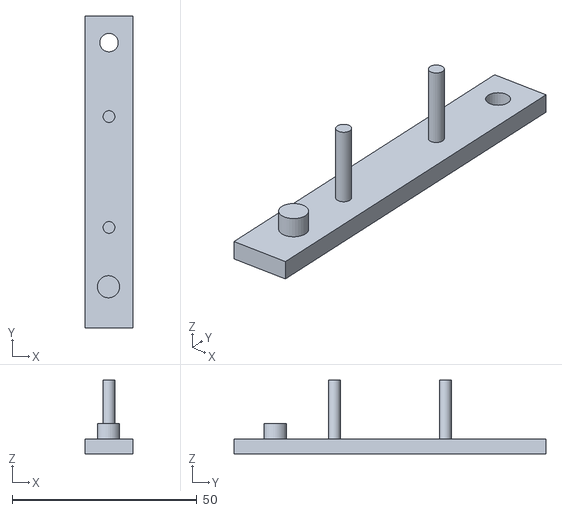
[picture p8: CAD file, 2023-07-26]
birdbooth_files/sensorcase_zwischenblatt.stl
13.0 x 84.4 x 20.0

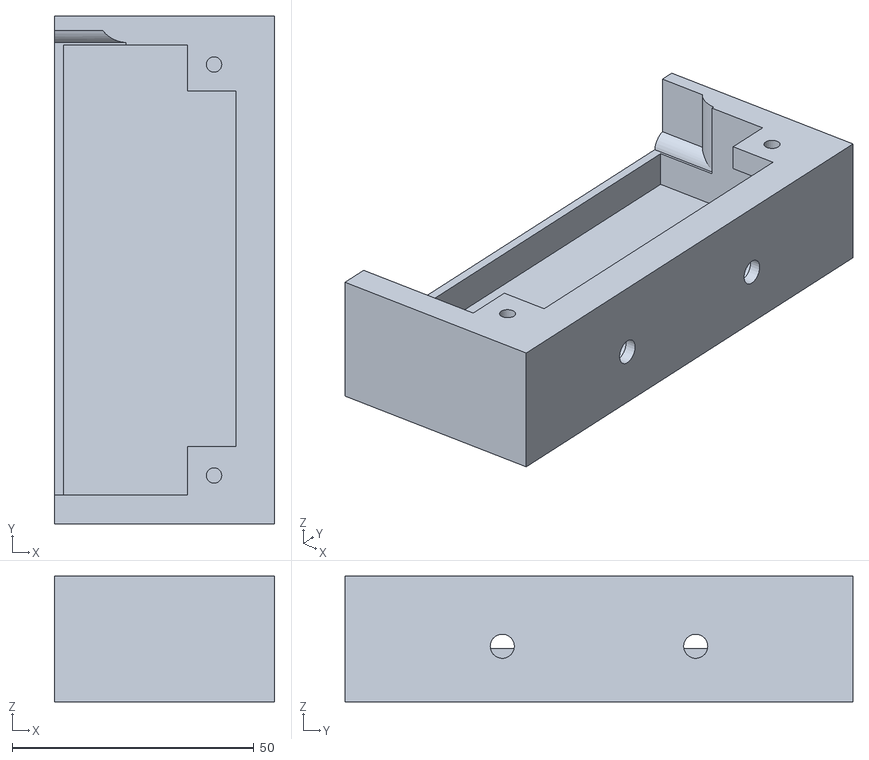
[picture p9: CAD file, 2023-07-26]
birdbooth_files/futterschale_unten.stl
45.5 x 105.0 x 26.0

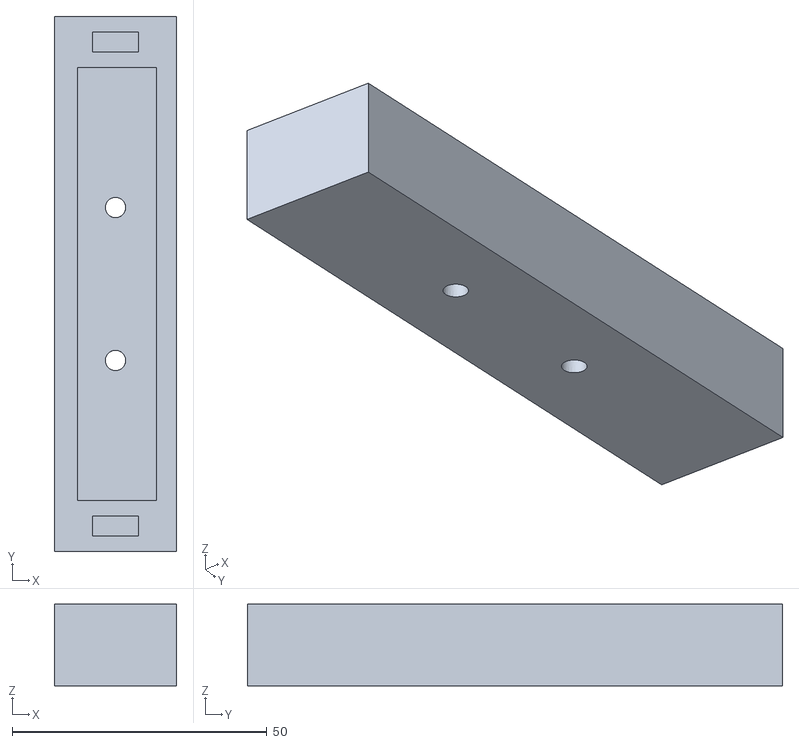
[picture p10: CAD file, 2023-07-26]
birdbooth_files/sensorcase_deckel.stl
24.0 x 105.0 x 16.0

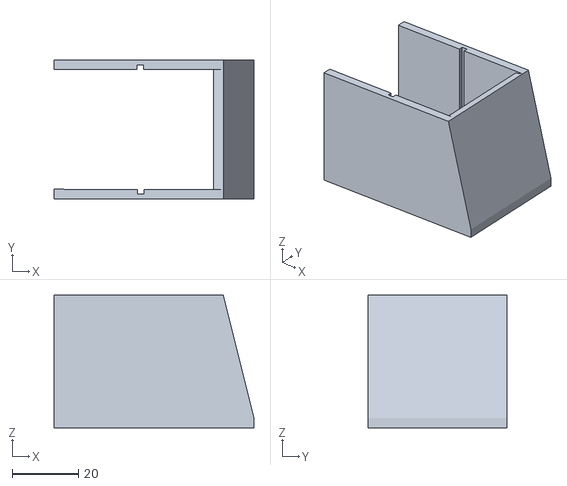
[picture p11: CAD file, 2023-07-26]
birdbooth_files/cam-case.stl
60.2 x 42.0 x 40.0
